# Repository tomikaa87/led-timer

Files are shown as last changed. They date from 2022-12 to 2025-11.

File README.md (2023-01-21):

# led-timer
Programmable timer for low voltage LED lights (e.g. christmas LED strings) with a Microchip PIC16.

**This project is in work-in-progress state**

# Features:
* Sophisticated scheduling system - you can choose from 48 individual 30 minute-length intervals to turn on the LED output
* Controllable LED brightness via PWM (Pulse Width Modulation) in 255 steps
* Dedicated LED driver circuit on the output
* Low power microcontroller - battery-friendly power consumption (LED output current not included)
  * 4 mA (screen on)
  * 0.2 mA (screen off)
  * ~6 μA (deep-sleep, only time-keeping) - more than 2 years from a standard CR2032 lithium battery
* Easy-to-use and intuitive user interface:
  * 3 buttons for changing settings, toggling the output etc.
  * OLED screen with schedule, output state, battery level indication and more
  * Each screen shows a legend for individual key functions
* Backup battery - timekeeping and changing settings work without external power

A custom-made PCB and a 3D-printable enclosure is still in development and should be published soon.

# Case

I've made a simple 3D-printable case in FreeCAD. It's a two-part design which can be assembled using M2 self-tapping screws.

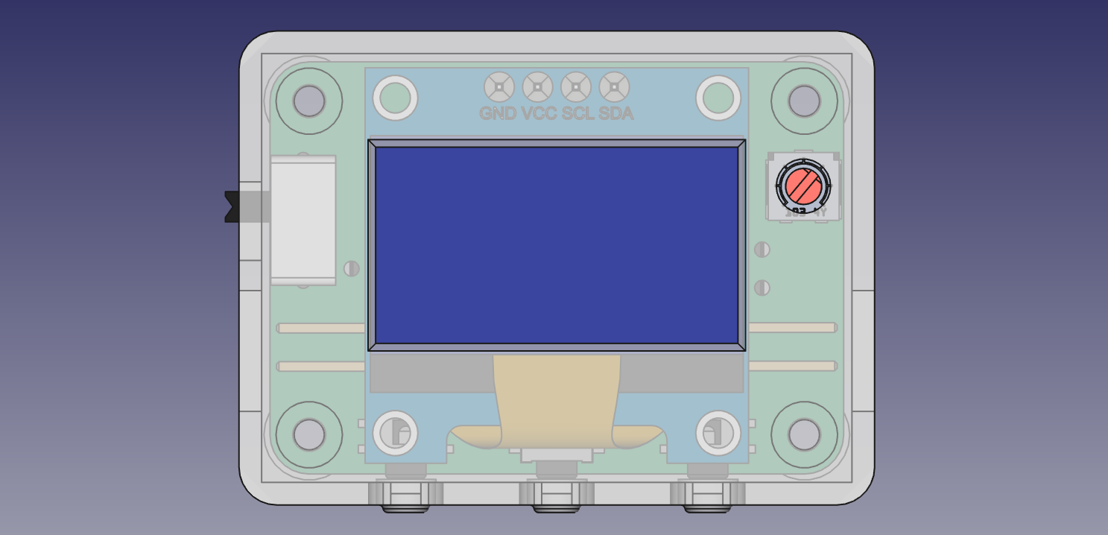
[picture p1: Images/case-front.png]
Front

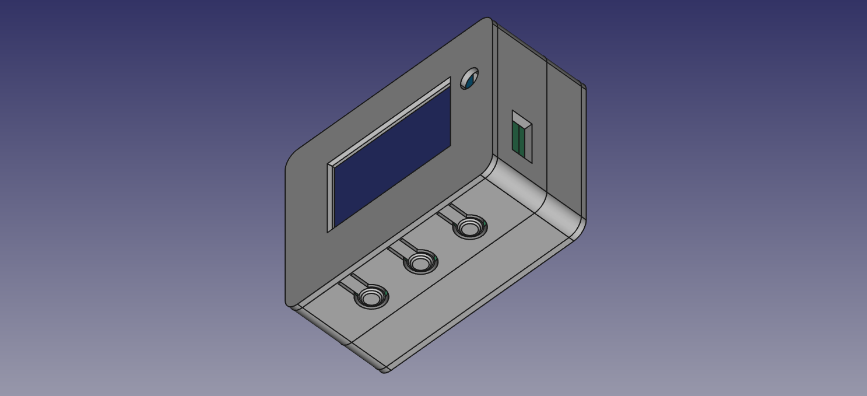
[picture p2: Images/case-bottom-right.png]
Bottom-right

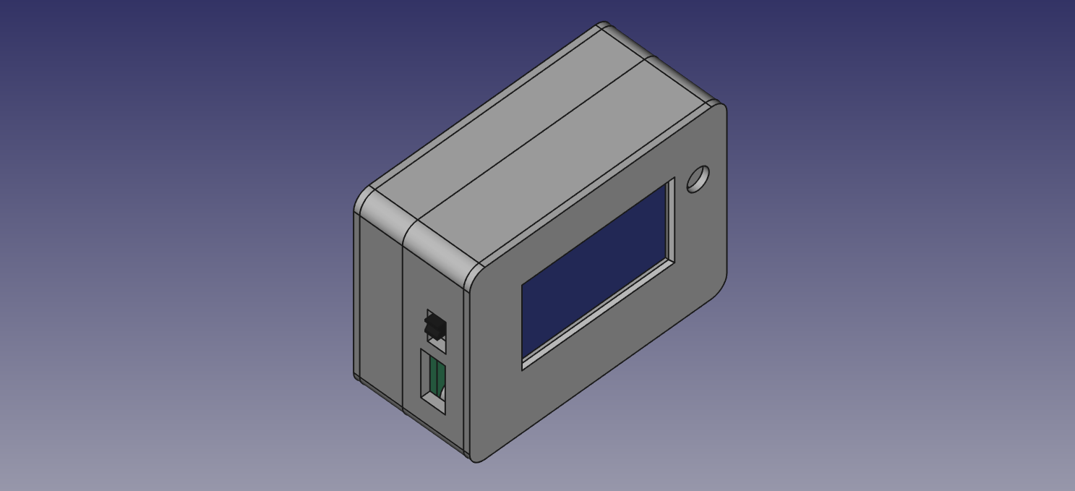
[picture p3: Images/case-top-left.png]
Top-left

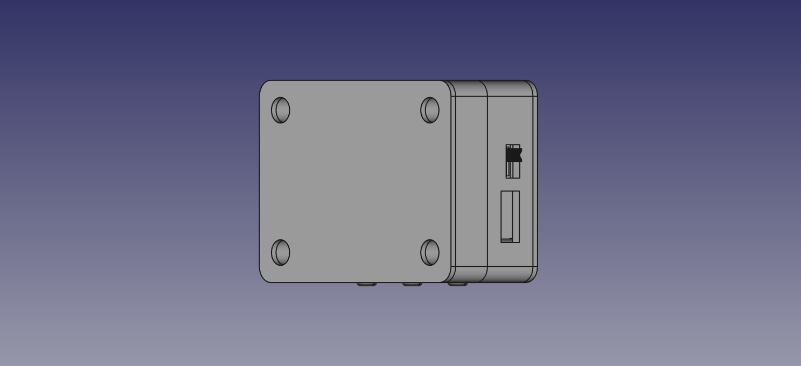
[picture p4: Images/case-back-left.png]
Back-left

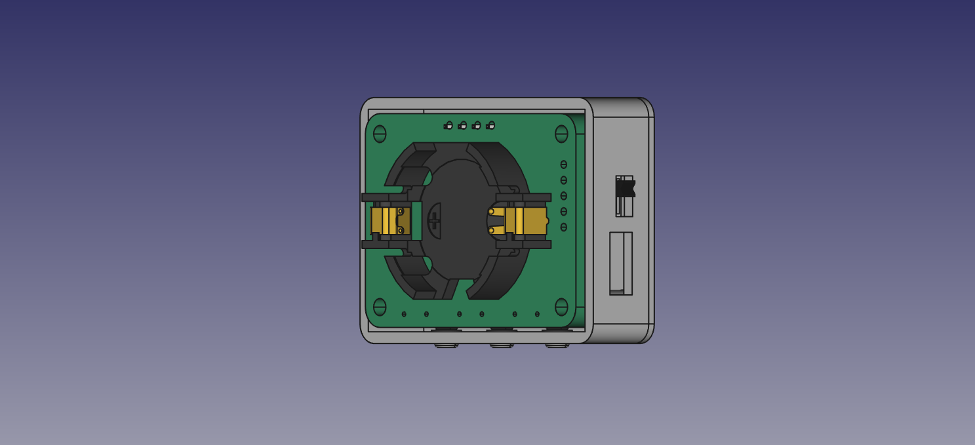
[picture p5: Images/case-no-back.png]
Without back cover


# PCB

The first version of the PCB is a 4-layer design that can be manufactured for $2 at JLC PCB.
It's almost as small as the 0.96" SSD1306 OLED display module itself. Because different display modules have varying pinouts (VDD and GND swapped), the function of the first two pins are configurable via solder jumpers (JP1 and JP2).
The switch on the side can turn of the timer completely to conserve battery power while the timer is in storage.
The three buttons on the bottom are for navigation on the user interface.
The battery holder on the back side receives a standard CR2032 3V lithium cell.
The power input and LED output connectors are standard 2.54 mm pitch pin headers.

The interactive BOM can be accessed HERE

## 3D renders of the PCB

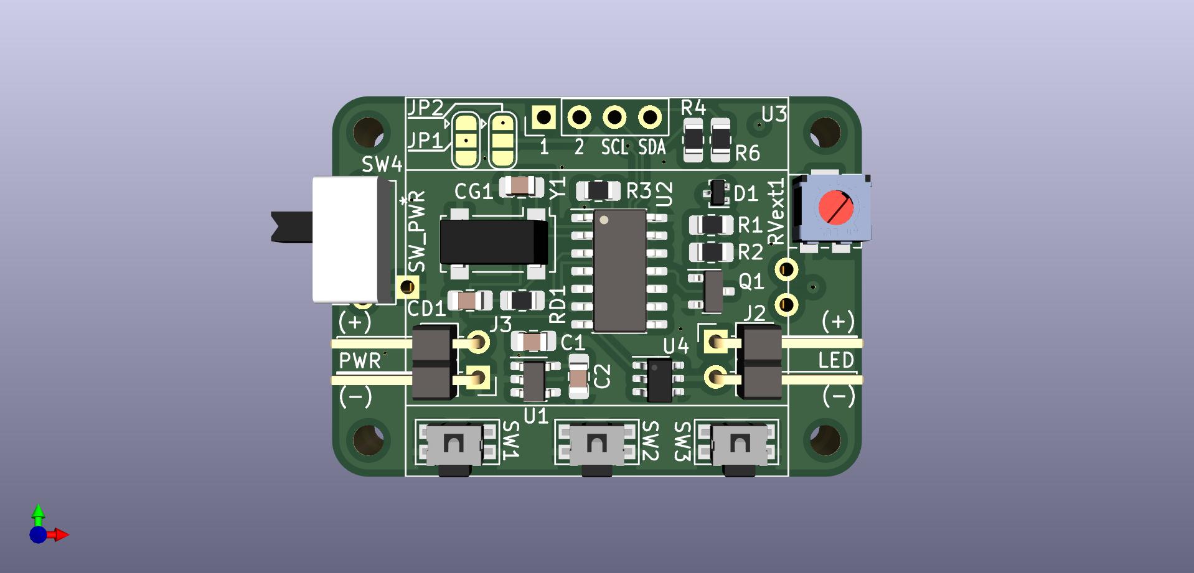
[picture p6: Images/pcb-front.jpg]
Front side


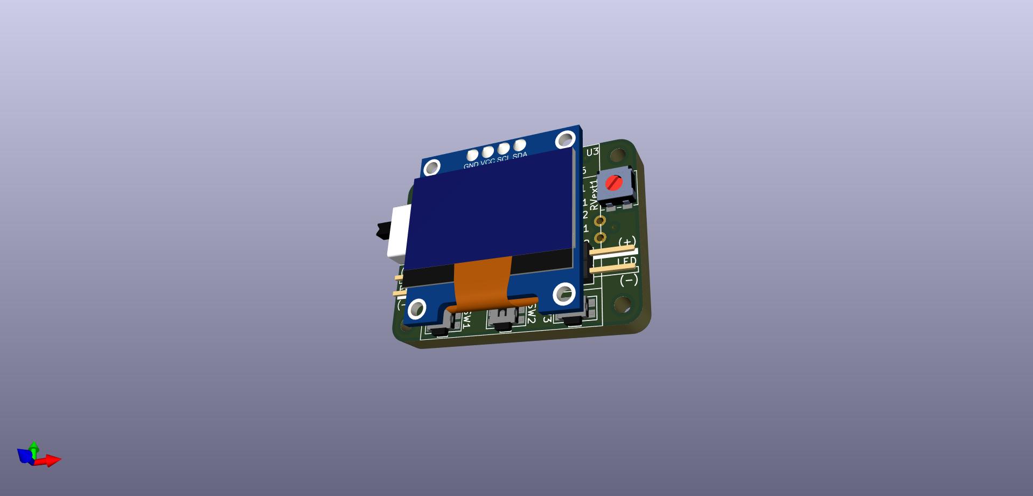
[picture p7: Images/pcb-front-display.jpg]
Front side with display


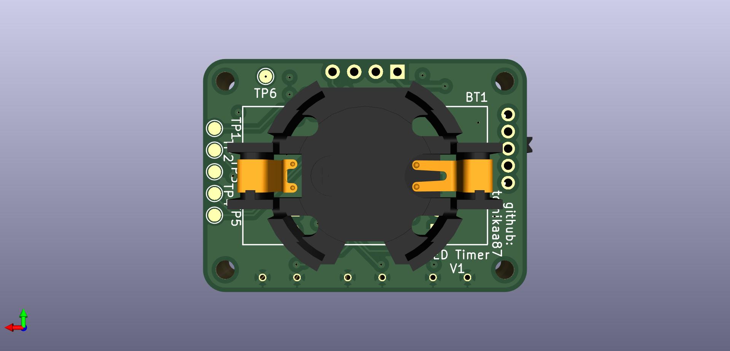
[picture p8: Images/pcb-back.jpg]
Back side


# Images of the prototype

## Main screen
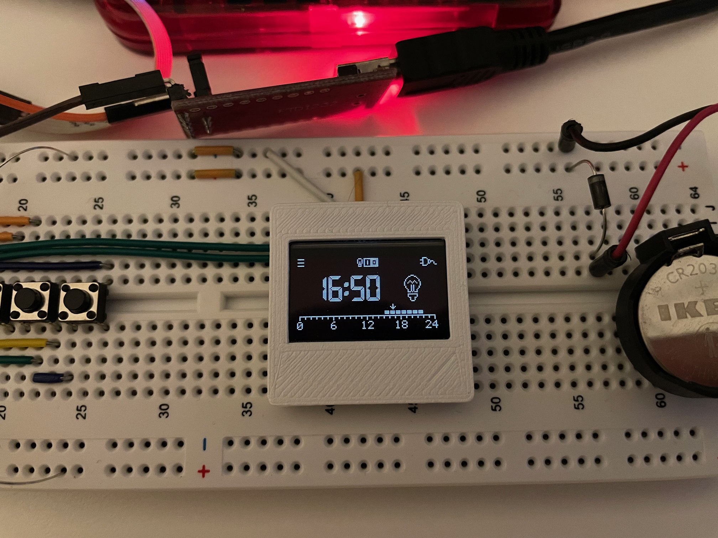
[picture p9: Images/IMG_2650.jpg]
Main screen


## Main screen functions explained
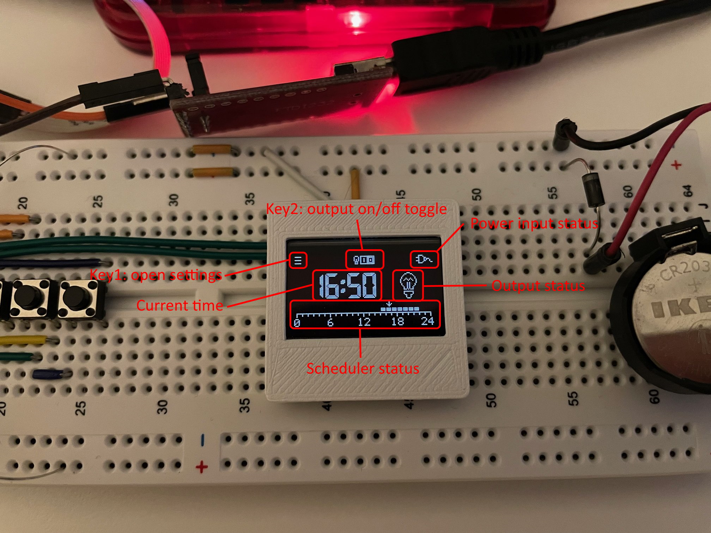
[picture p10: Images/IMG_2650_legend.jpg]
Main screen functions


## Settings screen
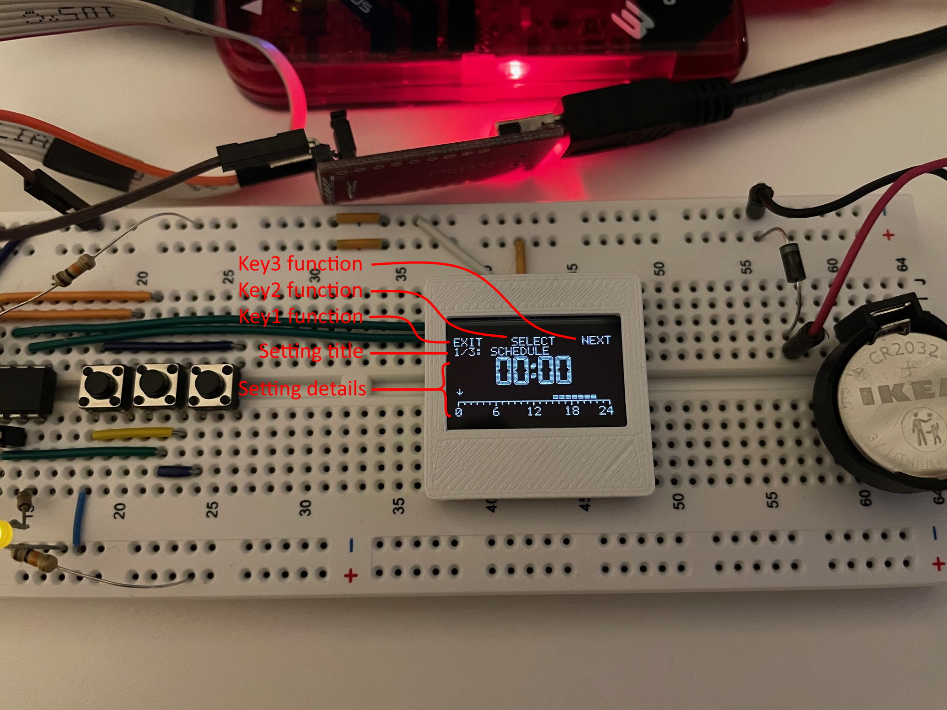
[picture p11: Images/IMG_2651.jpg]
Settings screen


## Scheduler settings
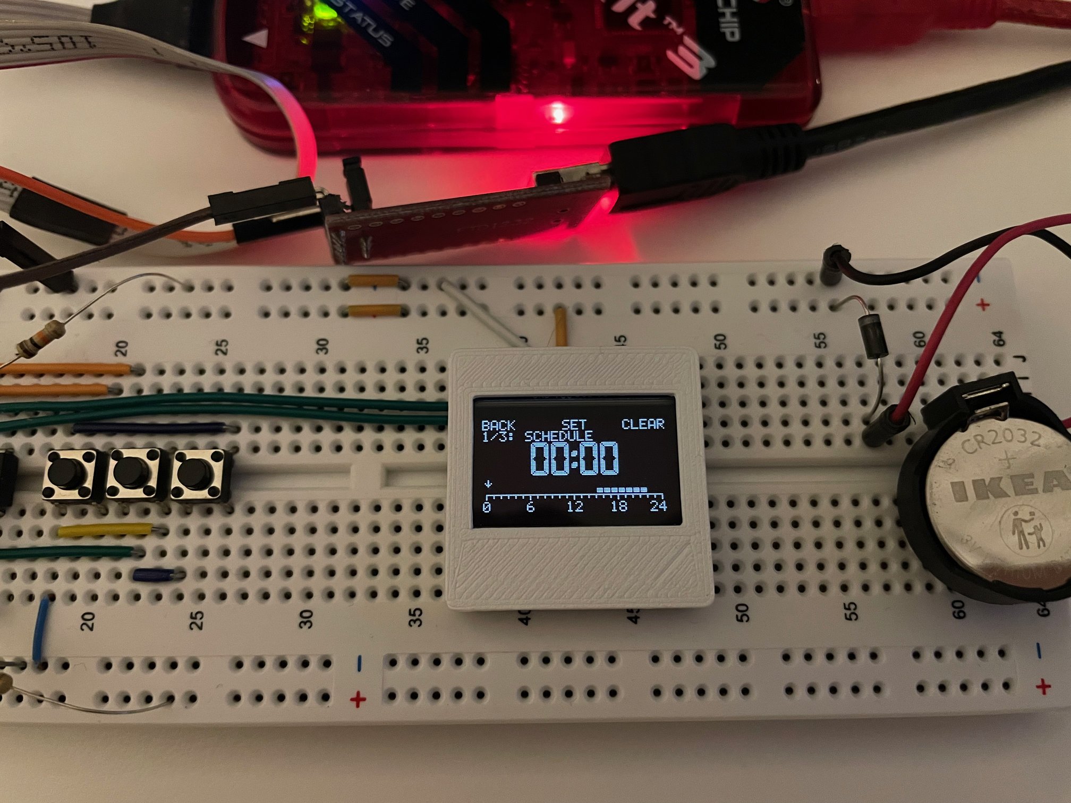
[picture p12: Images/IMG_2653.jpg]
Scheduler settings


## LED output brightness setting
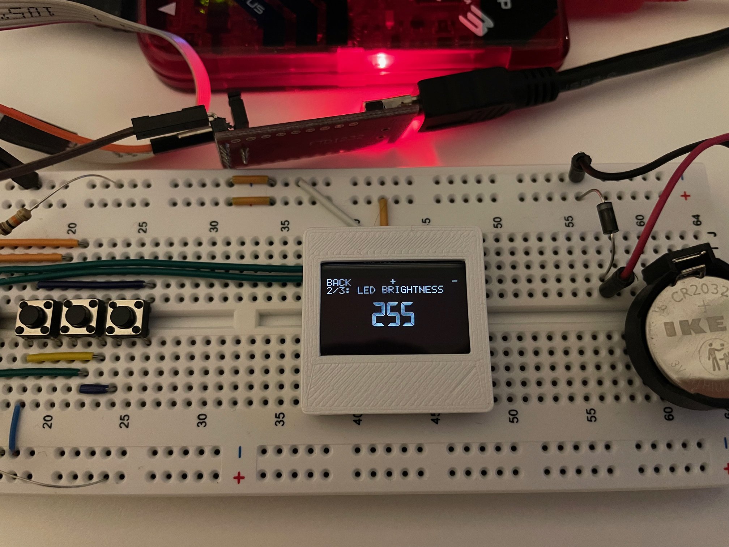
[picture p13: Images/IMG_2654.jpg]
LED brightness setting


## Clock setting
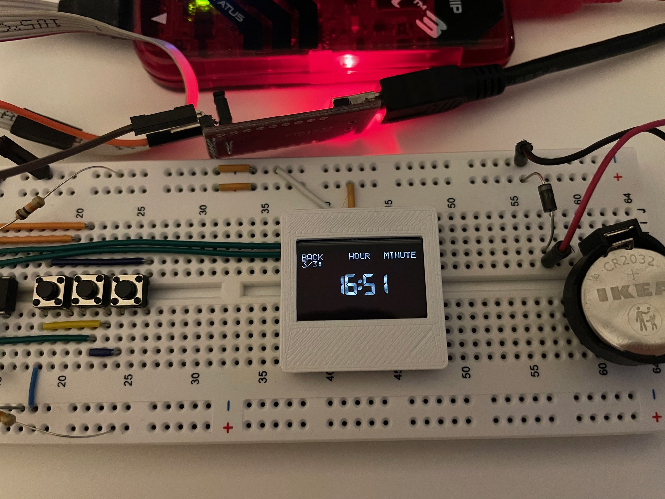
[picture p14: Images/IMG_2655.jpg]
Clock setting


## Prototype setup
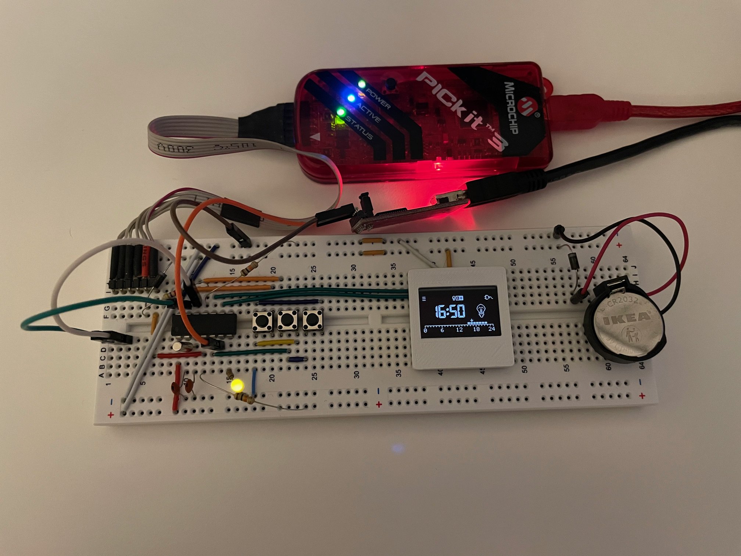
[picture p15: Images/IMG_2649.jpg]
Prototype setup


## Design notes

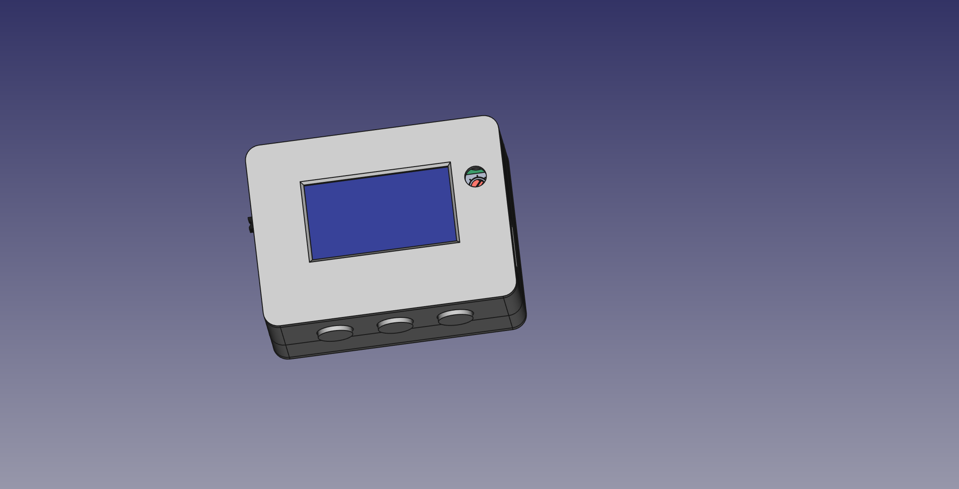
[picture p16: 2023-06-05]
Images/case-v1-front.png

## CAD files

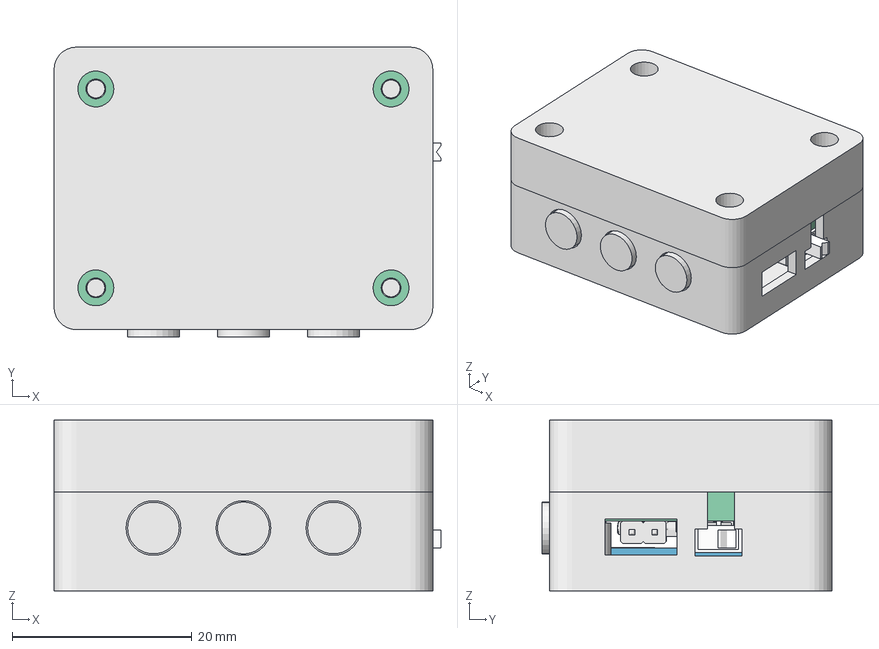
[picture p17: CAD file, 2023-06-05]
Hardware/LEDTimer-Case-v1.FCStd
43.0 x 32.2 x 19.0 mm
Pcb_6a3c
U1_SOT_23_5_c919dfabb42d
R6_R_0805_2012Metric_913303a1058b x 7
ST-4EA
ST-4EA001
ST-4EA002
ST-4EA003
ST-4EA004
ST-4EA005
C2_C_0805_2012Metric_91cd6132d048 x 4
SW3_YD-3414 - Side SMD Switch _6de035d26ca9 x 3
Q1_SOT_23_be697421db99
SW4_1825232-1 v7_d91099a16907
J3_PinHeader_1x02_P254mm_Horizontal_407d359f6e54 x 2
smq32s_корпус
smq32s_контакт
smq32s_контакт001
smq32s_контакт002
smq32s_контакт003
board
board001
board002
board003
board004
board005
board006
board007
board008
screen
screen001
screen002
pin_header
pin_header001
pin_header002
pin_header003
pin_header004
pin_header005
pin_header006
pin_header007
soldering
soldering001
soldering002
soldering003
smd_capacitor
smd_capacitor001
smd_capacitor002
smd_capacitor (1)
smd_capacitor (1)001
smd_capacitor (1)002
914_smd_resistor
914_smd_resistor001
914_smd_resistor002
472_smd_resistor
472_smd_resistor001
472_smd_resistor002
472_smd_resistor004
472_smd_resistor005
472_smd_resistor006
472_smd_resistor008
472_smd_resistor009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

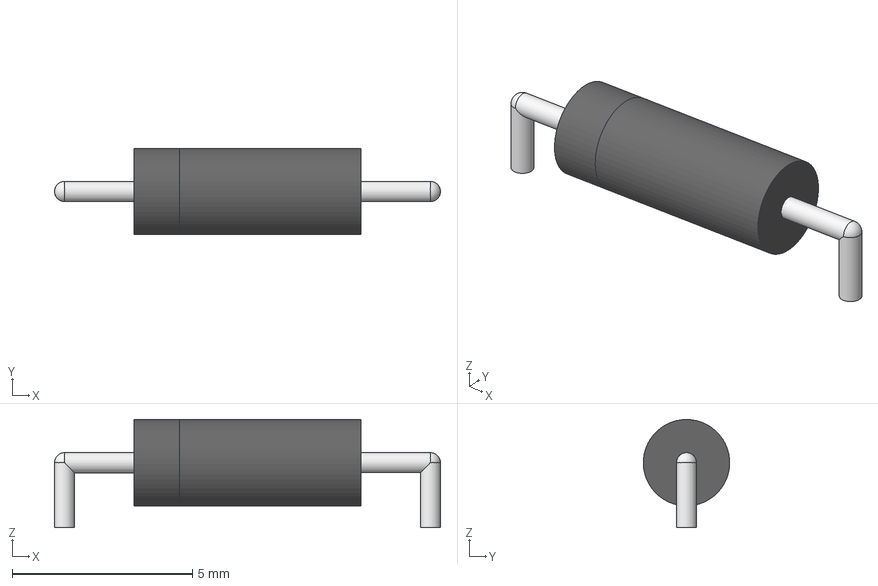
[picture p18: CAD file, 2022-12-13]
Hardware/LEDTimerLite/Batt_Renata_HU2032-LF/eec.models/Renata_-_HU2032-LF.step
10.7 x 2.40 x 3.00 mm

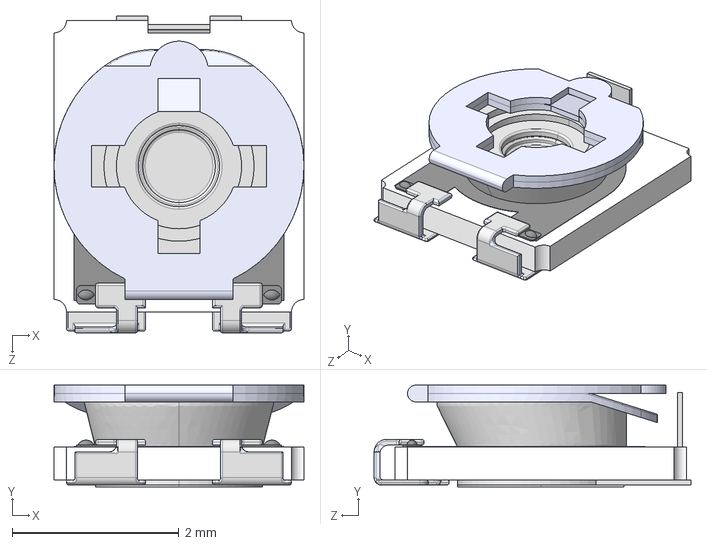
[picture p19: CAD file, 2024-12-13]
Hardware/LEDTimerLite/LIB_TC33X-2-101E/TC33X-2-101E.stp
3.00 x 1.22 x 3.80 mm

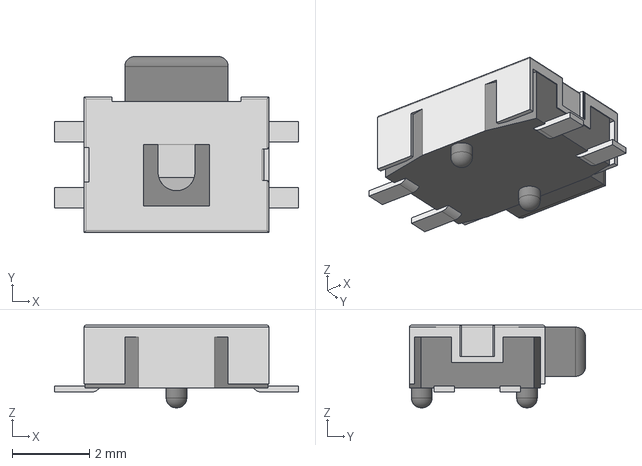
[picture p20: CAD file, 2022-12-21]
Hardware/LEDTimerLite/YD-3414 - Side SMD Switch .stp
6.30 x 4.55 x 2.13 mm

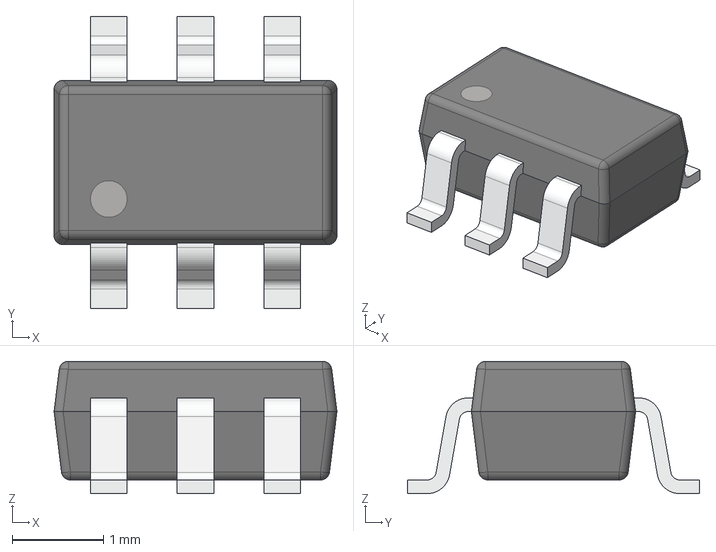
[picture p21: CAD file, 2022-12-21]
Hardware/LEDTimerLite/SC-74-6.stp
3.10 x 3.20 x 1.45 mm

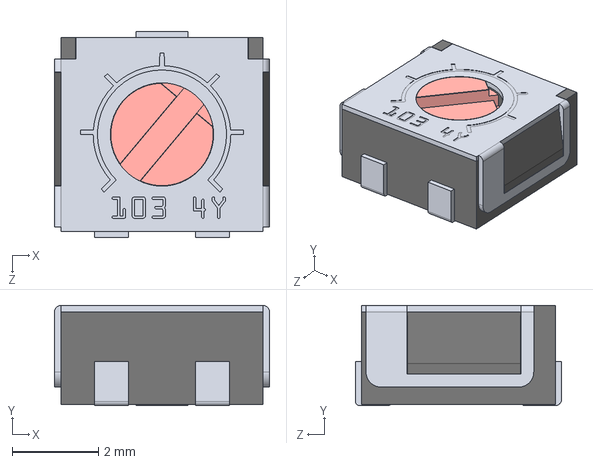
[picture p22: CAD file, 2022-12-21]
Hardware/LEDTimerLite/ST-4EA.STEP
5.00 x 2.33 x 4.80 mm

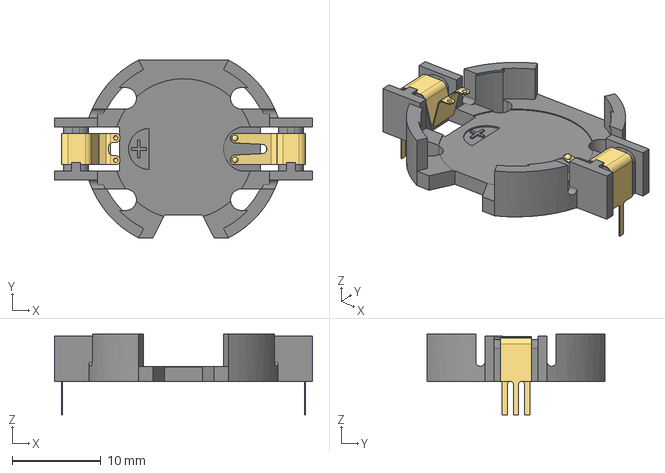
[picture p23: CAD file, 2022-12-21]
Hardware/LEDTimerLite/BU2032-1-HD-G.stp
29.0 x 20.0 x 9.05 mm

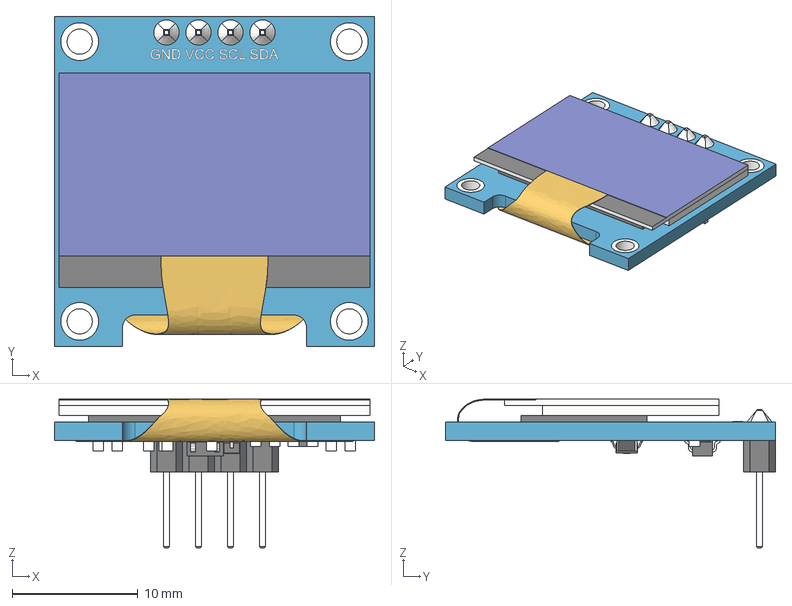
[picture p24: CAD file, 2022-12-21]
Hardware/LEDTimerLite/SSD1306_OLED_Display(128x64).step
25.4 x 26.2 x 11.8 mm
board
screen
pin_header
soldering
smd_capacitor
smd_capacitor (1)
914_smd_resistor
472_smd_resistor x 3
t4_smd_diode
smd_capacitor (2)
smd_capacitor (3)
smd_capacitor (4)
smd_capacitor (5)
smd_capacitor (6)
472_smd_resistor (1)
SOT-23_XC6206 v3
smd_capacitor (7)
flat_cable

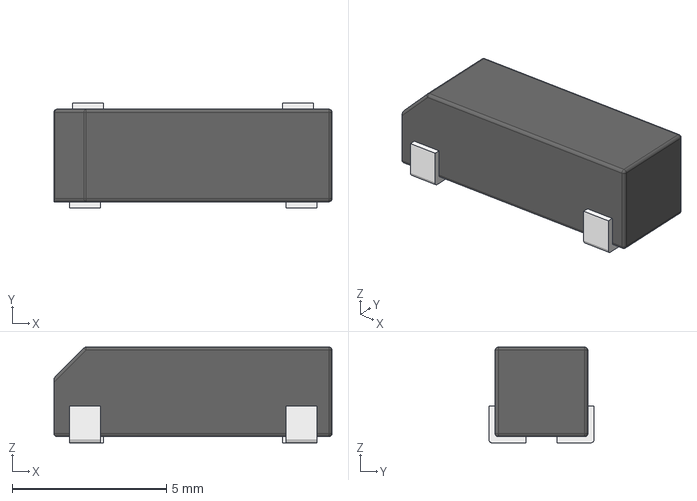
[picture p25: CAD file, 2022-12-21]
Hardware/LEDTimerLite/sqm32s.stp
9.00 x 3.40 x 3.10 mm
smq32s_контакт x 4

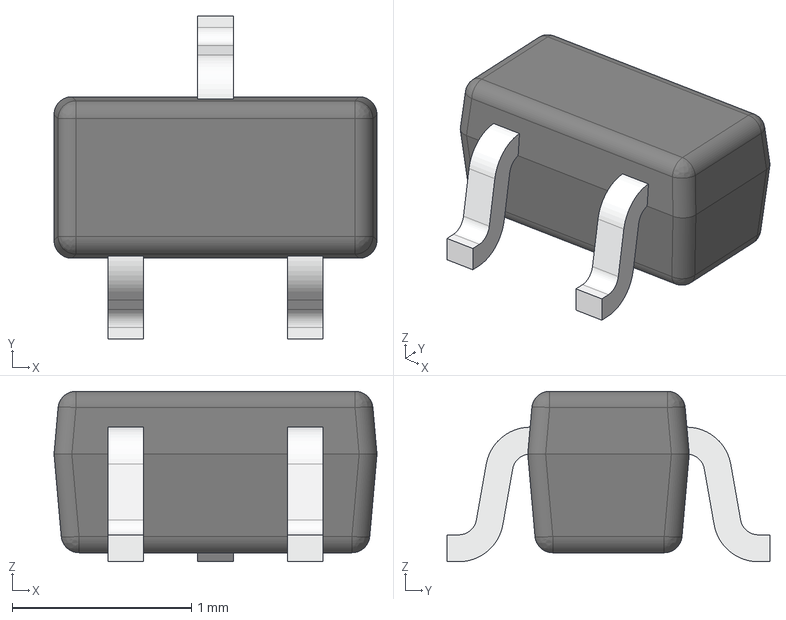
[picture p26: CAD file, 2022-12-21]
Hardware/LEDTimerLite/SC-75.stp
1.80 x 1.80 x 0.95 mm

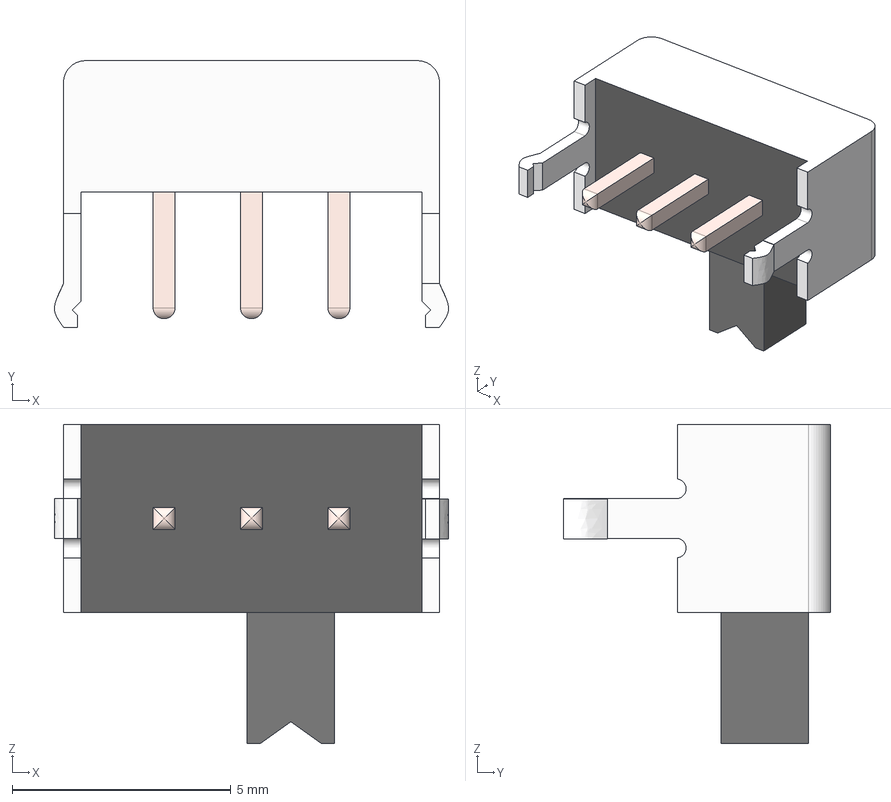
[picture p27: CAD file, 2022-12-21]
Hardware/LEDTimerLite/1825232-1 v7.step
9.01 x 6.10 x 7.30 mm

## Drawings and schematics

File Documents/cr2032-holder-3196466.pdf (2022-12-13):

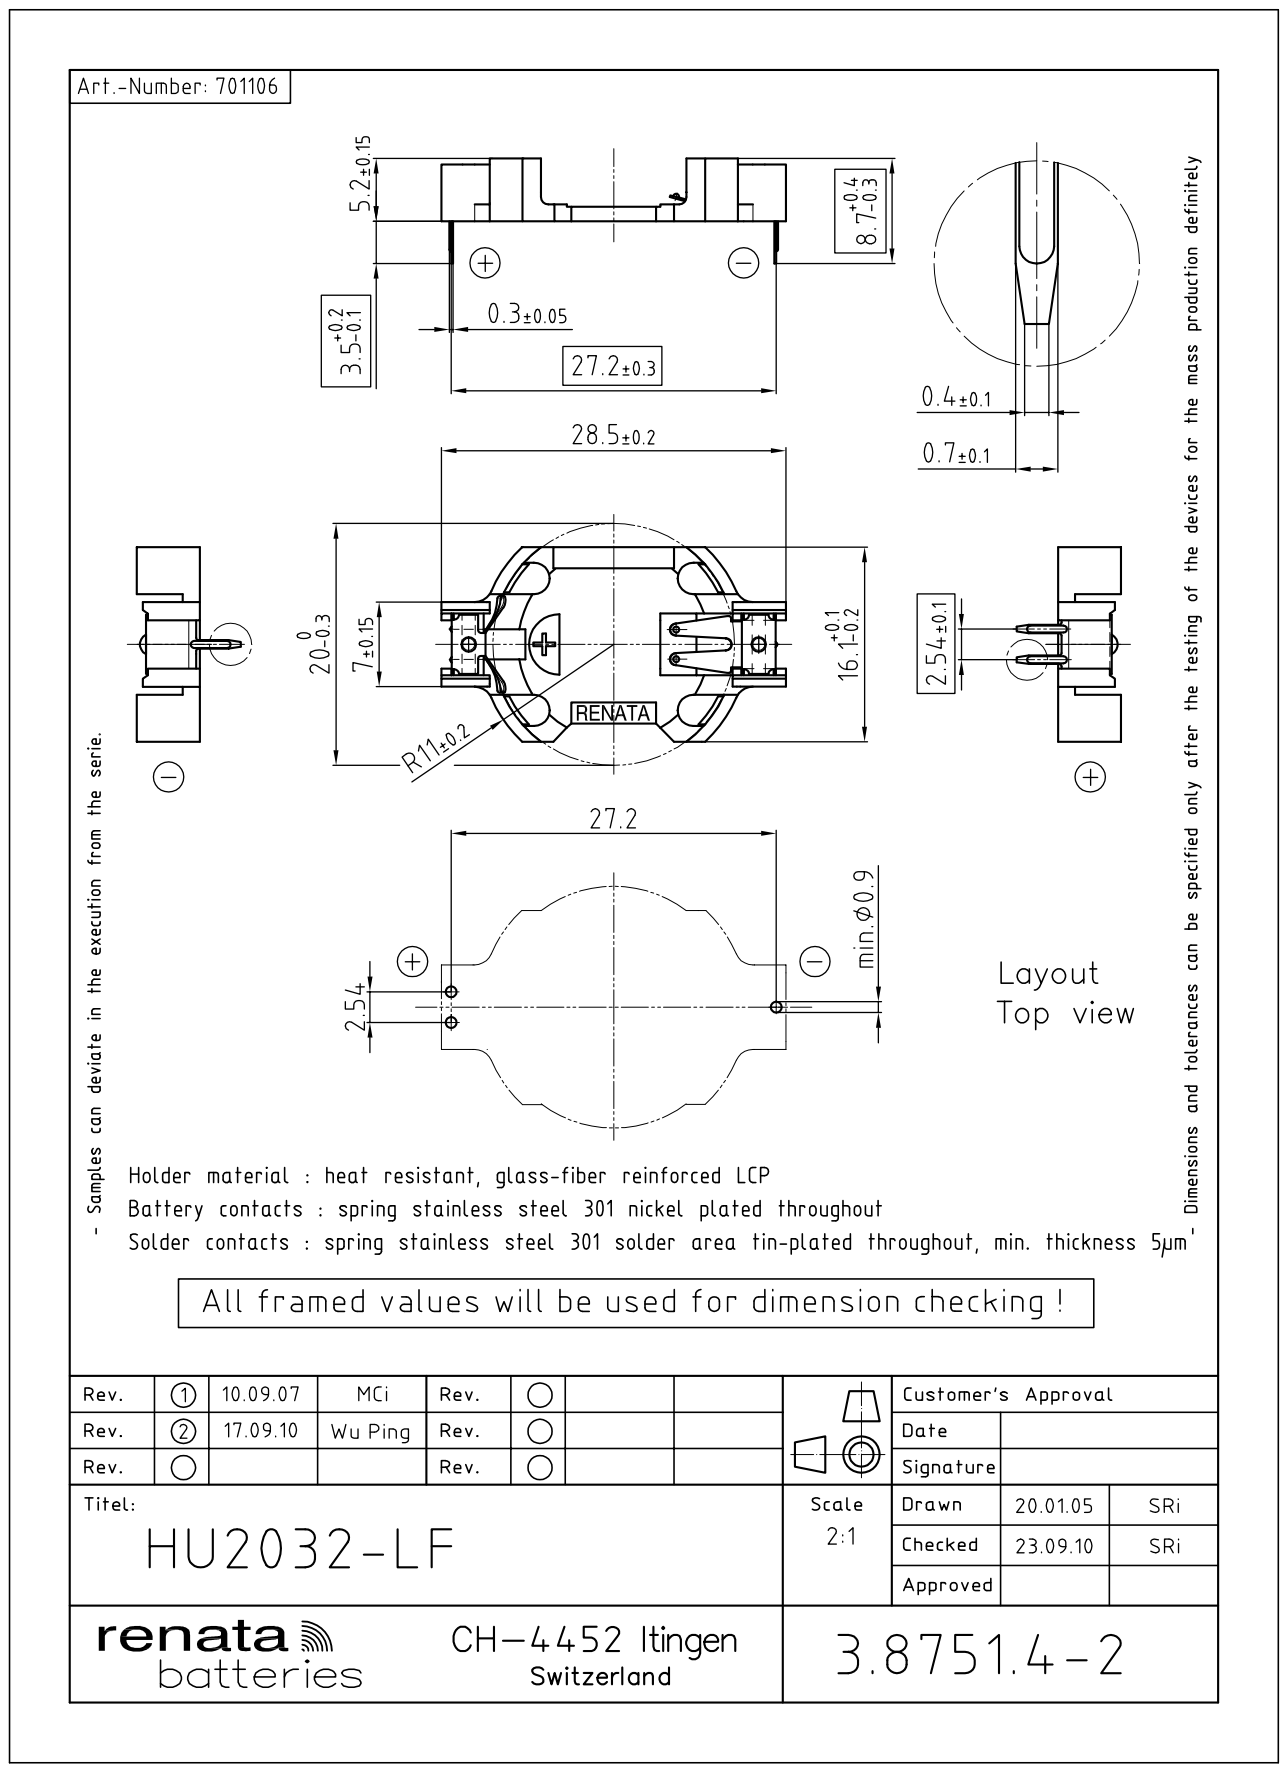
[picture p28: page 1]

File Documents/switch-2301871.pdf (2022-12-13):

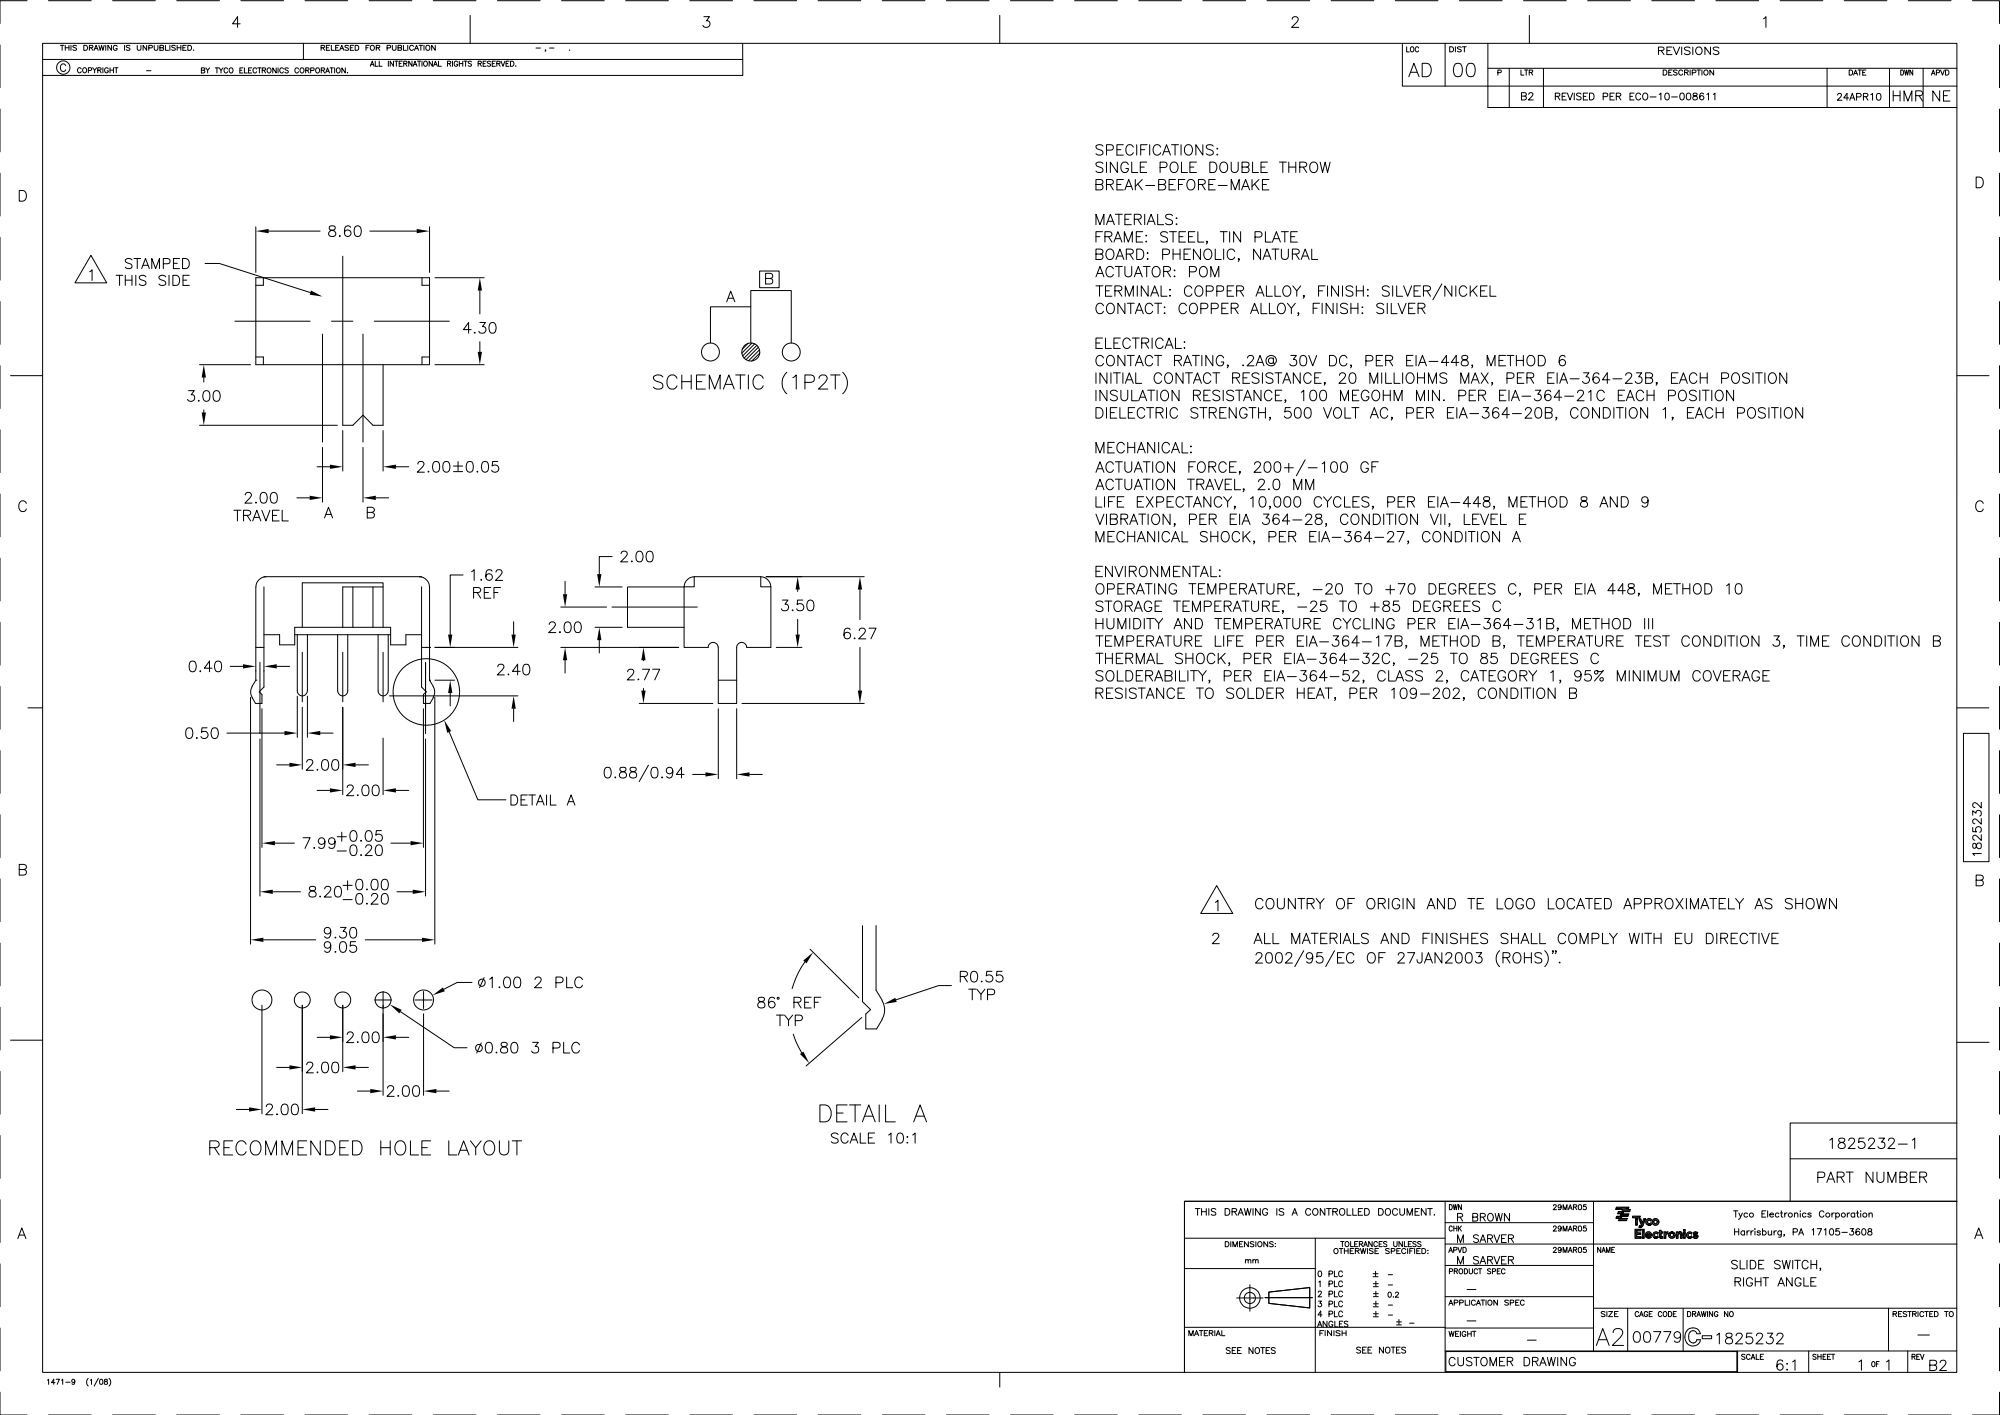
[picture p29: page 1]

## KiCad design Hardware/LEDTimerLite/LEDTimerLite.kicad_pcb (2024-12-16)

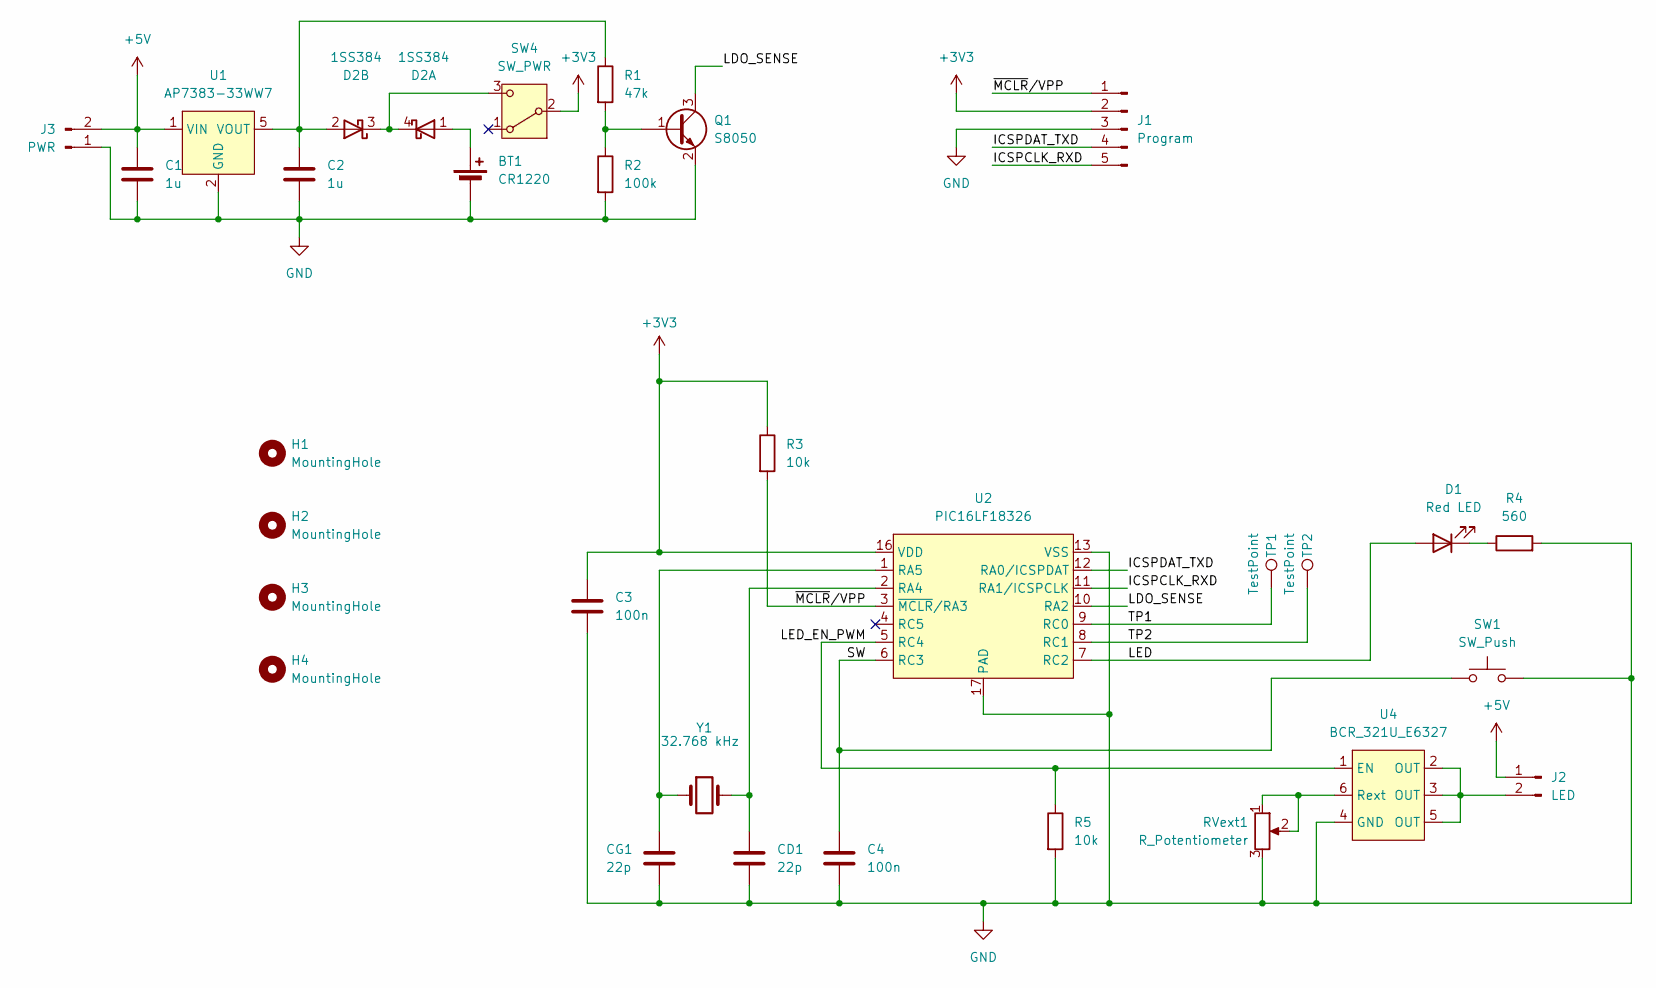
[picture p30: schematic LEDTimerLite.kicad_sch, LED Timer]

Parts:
BT1: CR1220; BatteryHolder_Keystone_3001_1x12mm; mouser part number 614-HU2032-LF; mouser description Coin Cell Battery Holders THRU HOLE FOR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
C1, C2: 1u; C_0805_2012Metric_Pad1.18x1.45mm_HandSolder
C3, C4: 100n; C_0805_2012Metric_Pad1.18x1.45mm_HandSolder
CD1: 22p; C_0805_2012Metric_Pad1.18x1.45mm_HandSolder
CG1: 22p; C_0805_2012Metric_Pad1.18x1.45mm_HandSolder
D1: Red LED; LED_0805_2012Metric_Pad1.15x1.40mm_HandSolder
D2: 1SS384; SOT-343_SC-70-4
H1, H2, H3, H4: MountingHole; MountingHole_2.2mm_M2_Pad_Via
J1: Program; PinHeader_1x05_P2.54mm_Vertical
J2: LED; PinHeader_1x02_P2.54mm_Horizontal
J3: PWR; PinHeader_1x02_P2.54mm_Horizontal
Q1: S8050; SOT-23
R1: 47k; R_0805_2012Metric_Pad1.20x1.40mm_HandSolder
R2: 100k; R_0805_2012Metric_Pad1.20x1.40mm_HandSolder
R3, R5: 10k; R_0805_2012Metric_Pad1.20x1.40mm_HandSolder
R4: 560; R_0805_2012Metric_Pad1.20x1.40mm_HandSolder
RVext1: R_Potentiometer; Potentiometer_Bourns_TC33X_Vertical
SW1: SW_Push; SW_SPST_TL3305A
SW4: SW_PWR; 1825232-1
TP1, TP2: TestPoint; TestPoint_Pad_D1.5mm
U1: AP7383-33WW7; SOT-23-5
U2: PIC16LF18326; UQFN-16-1EP_4x4mm_P0.65mm_EP2.6x2.6mm
U4: BCR_321U_E6327; SC-74-6_1.55x2.9mm_P0.95mm
Y1: 32.768 kHz; Crystal_SMD_MicroCrystal_CC8V-T1A-2Pin_2.0x1.2mm_HandSolder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

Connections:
+3V3: C3.1, J1.2, R3.1, SW4.2 (B), U2.16 (VDD)
+5V: C1.1, J2.1, J3.2, U1.1 (VIN)
/ICSPCLK_RXD: J1.5, U2.11 (RA1/ICSPCLK)
/ICSPDAT_TXD: J1.4, U2.12 (RA0/ICSPDAT)
/LDO_SENSE: Q1.3 (C), U2.10 (RA2)
/LED: D1.2 (A), U2.7 (RC2)
/LED_EN_PWM: R5.1, U2.5 (RC4), U4.1 (EN)
/SW: C4.1, SW1.2, U2.6 (RC3)
/TP1: TP1.1, U2.9 (RC0)
/TP2: TP2.1, U2.8 (RC1)
/~MCLR/VPP: J1.1, R3.2, U2.3 (~MCLR/RA3)
GND: BT1.2 (-), C1.2, C2.2, C3.2, C4.2, CD1.2, CG1.2, J1.3, J3.1, Q1.2 (E), R2.2, R4.2, R5.2, RVext1.3, SW1.1, U1.2 (GND), U2.13 (VSS), U2.17 (PAD), U4.4 (GND)
unnamed: BT1.1 (+), D2.1 (A)
unnamed: D1.1 (K), R4.1
unnamed: D2.3 (K), D2.4 (K), SW4.3 (C)
unnamed: C2.1, D2.2 (A), R1.1, U1.5 (VOUT)
unnamed: J2.2, U4.2 (OUT), U4.3 (OUT), U4.5 (OUT)
unnamed: Q1.1 (B), R1.2, R2.1
unnamed: CD1.1, U2.2 (RA4), Y1.2
unnamed: CG1.1, U2.1 (RA5), Y1.1
unnamed: RVext1.1, RVext1.2, U4.6 (Rext)

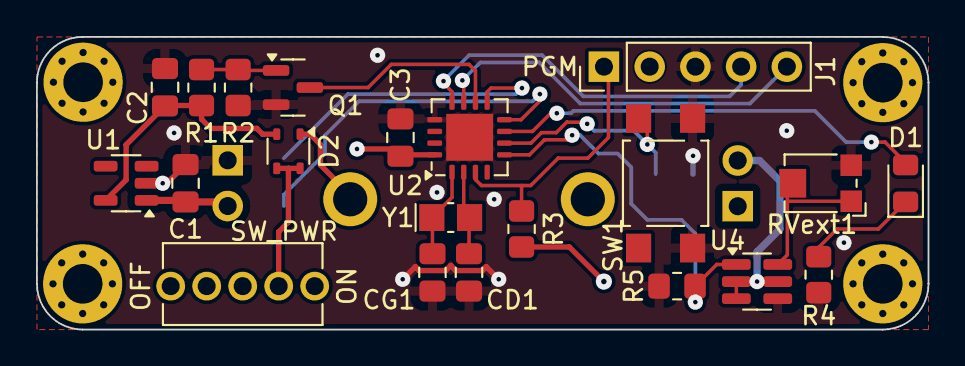
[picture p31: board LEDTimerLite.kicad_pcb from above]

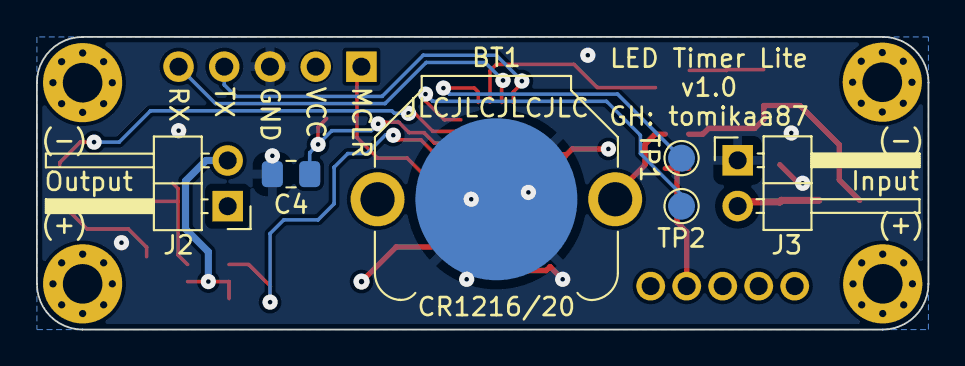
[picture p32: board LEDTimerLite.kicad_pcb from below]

Board: 4 copper layers, 49.5 x 16.3 mm, 31 parts (6 on the bottom side), 21 nets.

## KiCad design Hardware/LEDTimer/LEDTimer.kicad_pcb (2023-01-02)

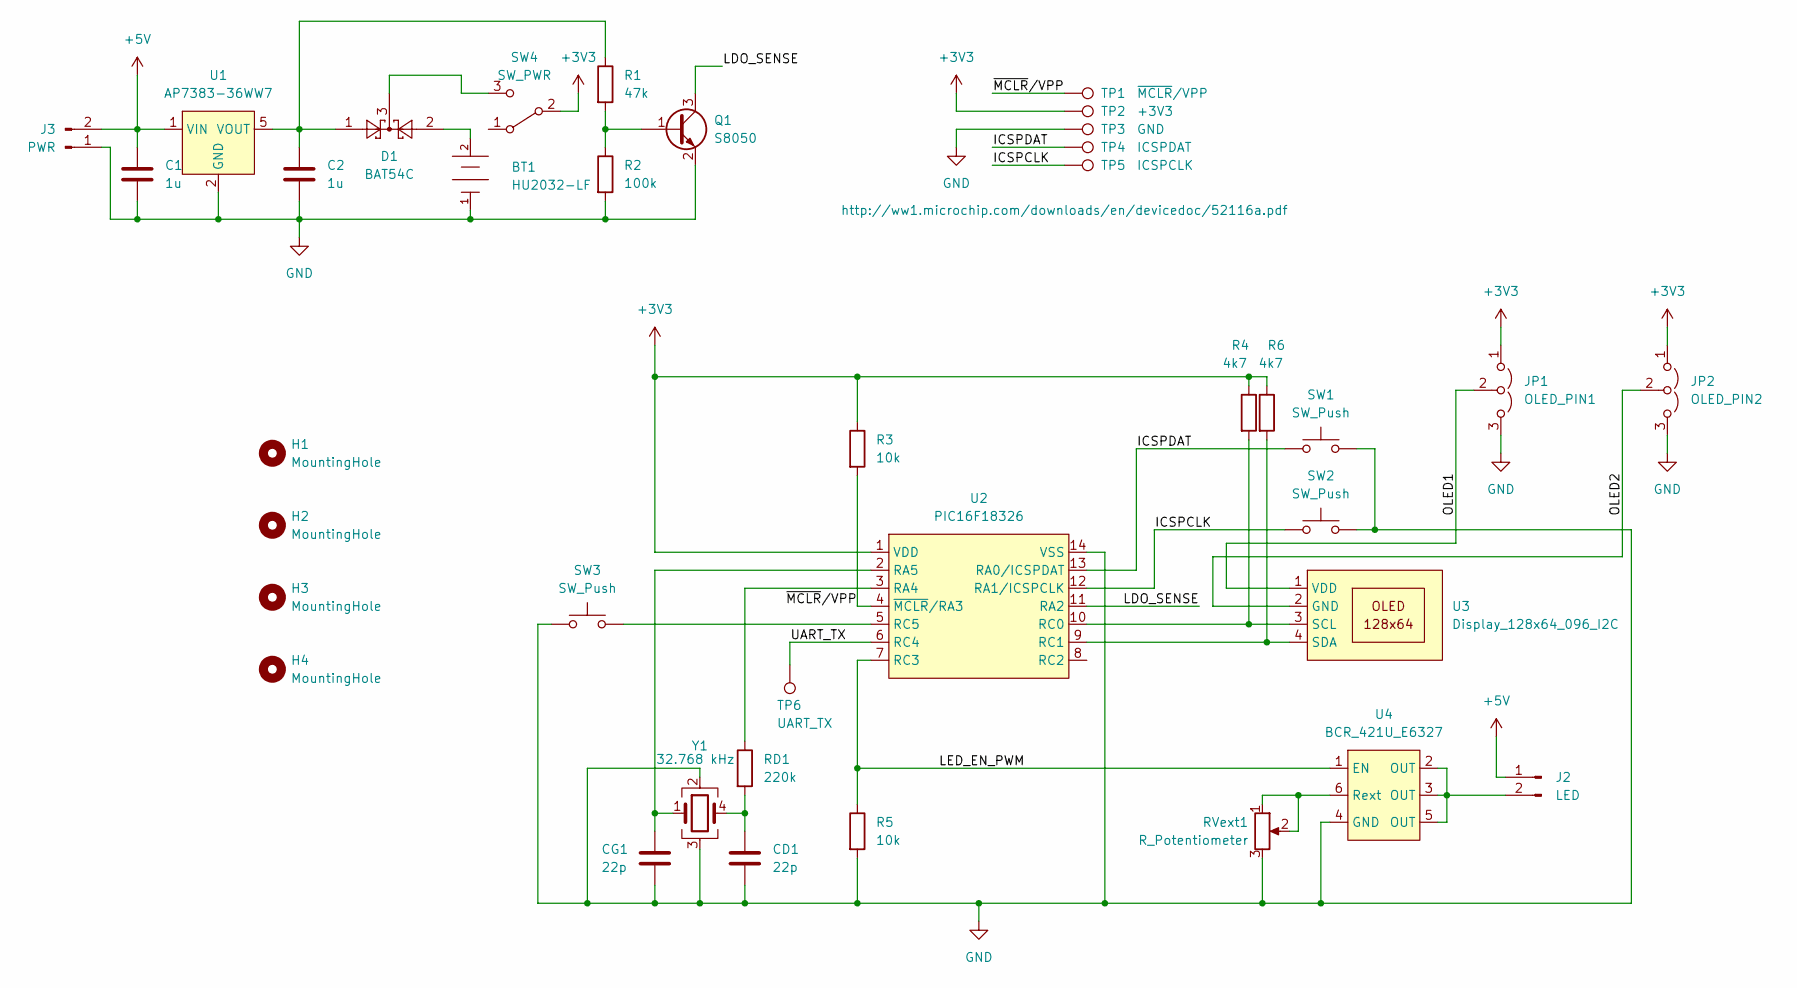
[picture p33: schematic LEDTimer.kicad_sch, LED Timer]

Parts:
BT1: HU2032-LF; Renata-HU2032-LF-0-0-0; mouser part number 614-HU2032-LF; mouser description Coin Cell Battery Holders THRU HOLE FOR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
C1, C2: 1u; C_0805_2012Metric_Pad1.18x1.45mm_HandSolder
CD1: 22p; C_0805_2012Metric_Pad1.18x1.45mm_HandSolder
CG1: 22p; C_0805_2012Metric_Pad1.18x1.45mm_HandSolder
D1: BAT54C; SOT-416
H1, H2, H3, H4: MountingHole; MountingHole_2.2mm_M2
J2: LED; PinHeader_1x02_P2.54mm_Horizontal
J3: PWR; PinHeader_1x02_P2.54mm_Horizontal
JP1: OLED_PIN1; SolderJumper-3_P1.3mm_Open_RoundedPad1.0x1.5mm
JP2: OLED_PIN2; SolderJumper-3_P1.3mm_Open_RoundedPad1.0x1.5mm
Q1: S8050; SOT-23
R1: 47k; R_0805_2012Metric_Pad1.20x1.40mm_HandSolder
R2: 100k; R_0805_2012Metric_Pad1.20x1.40mm_HandSolder
R3, R5: 10k; R_0805_2012Metric_Pad1.20x1.40mm_HandSolder
R4, R6: 4k7; R_0805_2012Metric_Pad1.20x1.40mm_HandSolder
RD1: 220k; R_0805_2012Metric_Pad1.20x1.40mm_HandSolder
RVext1: R_Potentiometer; Potentiometer_Vishay_TS53YJ_Vertical
SW1, SW2, SW3: SW_Push; EVQ9P701P
SW4: SW_PWR; 1825232-1
TP1: ~{MCLR}/VPP; TestPoint_Pad_D1.5mm
TP2: +3V3; TestPoint_Pad_D1.5mm
TP3: GND; TestPoint_Pad_D1.5mm
TP4: ICSPDAT; TestPoint_Pad_D1.5mm
TP5: ICSPCLK; TestPoint_Pad_D1.5mm
TP6: UART_TX; TestPoint_Pad_D1.5mm
U1: AP7383-36WW7; SOT-23-5
U2: PIC16F18326; SOIC-14_3.9x8.7mm_P1.27mm
U3: Display_128x64_096_I2C
U4: BCR_421U_E6327; SC-74-6_1.5x2.9mm_P0.95mm
Y1: 32.768 kHz; Crystal_SMD_Abracon_ABS25-4Pin_8.0x3.8mm

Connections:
+3V3: JP1.1 (A), JP2.1 (A), R3.1, R4.1, R6.1, SW4.2 (B), TP2.1, U2.1 (VDD)
+5V: C1.1, J2.1, J3.2, U1.1 (VIN)
/ICSPCLK: SW2.2, TP5.1, U2.12 (RA1/ICSPCLK)
/ICSPDAT: SW1.2, TP4.1, U2.13 (RA0/ICSPDAT)
/LDO_SENSE: Q1.3 (C), U2.11 (RA2)
/LED_EN_PWM: R5.1, U2.7 (RC3), U4.1 (EN)
/OLED1: JP1.2 (C), U3.1 (VDD)
/OLED2: JP2.2 (C), U3.2 (GND)
/UART_TX: TP6.1, U2.6 (RC4)
/~MCLR/VPP: R3.2, TP1.1, U2.4 (~MCLR/RA3)
GND: BT1.1 (CATHODE), C1.2, C2.2, CD1.2, CG1.2, J3.1, JP1.3 (B), JP2.3 (B), Q1.2 (E), R2.2, R5.2, RVext1.3, SW1.1, SW2.1, SW3.1, TP3.1, U1.2 (GND), U2.14 (VSS), U4.4 (GND), Y1.2, Y1.3
unnamed: BT1.2 (ANODE), D1.2
unnamed: C2.1, D1.1, R1.1, U1.5 (VOUT)
unnamed: CD1.1, RD1.2, Y1.4
unnamed: CG1.1, U2.2 (RA5), Y1.1
unnamed: D1.3, SW4.3 (C)
unnamed: J2.2, U4.2 (OUT), U4.3 (OUT), U4.5 (OUT)
unnamed: Q1.1 (B), R1.2, R2.1
unnamed: R4.2, U2.10 (RC0), U3.3 (SCL)
unnamed: R6.2, U2.9 (RC1), U3.4 (SDA)
unnamed: RD1.1, U2.3 (RA4)
unnamed: RVext1.1, RVext1.2, U4.6 (Rext)
unnamed: SW3.2, U2.5 (RC5)

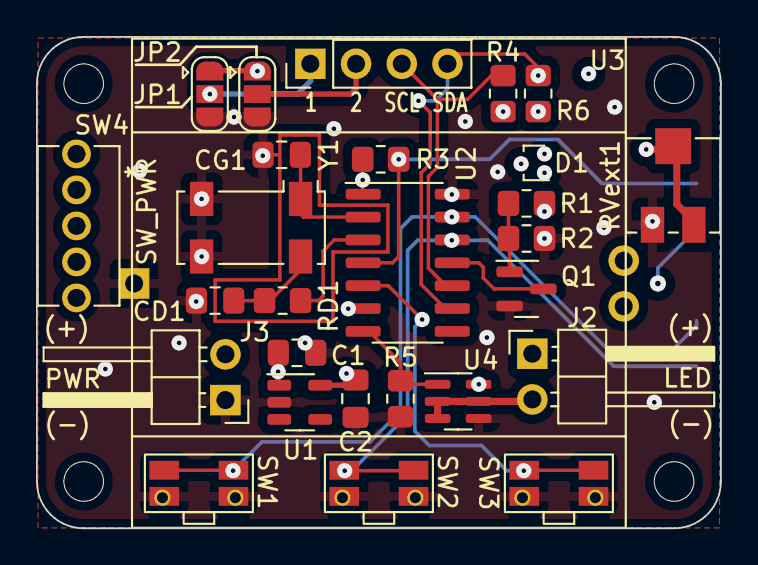
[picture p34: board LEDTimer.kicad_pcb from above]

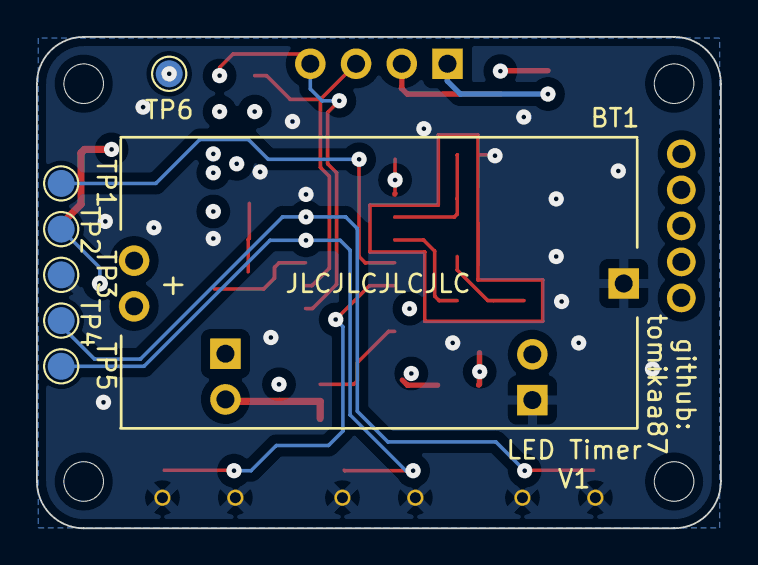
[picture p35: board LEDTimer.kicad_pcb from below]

Board: 4 copper layers, 38.0 x 27.3 mm, 38 parts (7 on the bottom side), 23 nets.

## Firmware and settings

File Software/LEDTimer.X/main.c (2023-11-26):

/**
  Generated Main Source File

  Company:
    Microchip Technology Inc.

  File Name:
    main.c

  Summary:
    This is the main file generated using PIC10 / PIC12 / PIC16 / PIC18 MCUs

  Description:
    This header file provides implementations for driver APIs for all modules selected in the GUI.
    Generation Information :
        Product Revision  :  PIC10 / PIC12 / PIC16 / PIC18 MCUs - 1.81.8
        Device            :  PIC16F18326
        Driver Version    :  2.00
*/

/*
    (c) 2018 Microchip Technology Inc. and its subsidiaries.

    Subject to your compliance with these terms, you may use Microchip software and any
    derivatives exclusively with Microchip products. It is your responsibility to comply with third party
    license terms applicable to your use of third party software (including open source software) that
    may accompany Microchip software.

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
    IN NO EVENT WILL MICROCHIP BE LIABLE FOR ANY INDIRECT, SPECIAL, PUNITIVE,
    INCIDENTAL OR CONSEQUENTIAL LOSS, DAMAGE, COST OR EXPENSE OF ANY KIND
    WHATSOEVER RELATED TO THE SOFTWARE, HOWEVER CAUSED, EVEN IF MICROCHIP
    HAS BEEN ADVISED OF THE POSSIBILITY OR THE DAMAGES ARE FORESEEABLE. TO
    THE FULLEST EXTENT ALLOWED BY LAW, MICROCHIP'S TOTAL LIABILITY ON ALL
    CLAIMS IN ANY WAY RELATED TO THIS SOFTWARE WILL NOT EXCEED THE AMOUNT
    OF FEES, IF ANY, THAT YOU HAVE PAID DIRECTLY TO MICROCHIP FOR THIS
    SOFTWARE.
*/

#include "mcc_generated_files/mcc.h"

#include "Clock.h"
#include "Config.h"
#include "Graphics.h"
#include "Keypad.h"
#include "OutputController.h"
#include "Settings.h"
#include "SSD1306.h"
#include "System.h"
#include "Text.h"
#include "UI.h"

// FIXME for testing
#include "SunsetSunrise.h"

#include <stdio.h>
#include <stdbool.h>

static struct MainContext
{
    volatile bool adcConversionFinished;
} context = {
    .adcConversionFinished = false
};

void __interrupt() isr(void)
{
    if (IOCIE && IOCIF) {
        // RA0 IOC - SW1
        if (IOCAF0) {
            IOCAF0 = 0;
            System_handleExternalWakeUp();
        }

        // RA1 IOC - SW2
        if (IOCAF1) {
            IOCAF1 = 0;
            System_handleExternalWakeUp();
        }

        // RC5 IOC - SW3
        if (IOCCF5) {
            IOCCF5 = 0;
            System_handleExternalWakeUp();
        }

        // RA2 IOC - LDO_SENSE
        if (IOCAF2) {
            IOCAF2 = 0;
            System_handleLDOSenseInterrupt();
        }
    }

    if (PEIE) {
        if (ADIE && ADIF) {
            ADIF = 0;
            System_handleADCInterrupt(((uint16_t)ADRESH) << 8 | ADRESL);
            context.adcConversionFinished = true;
        }

        if (TMR4IE & TMR4IF) {
            TMR4IF = 0;
            Clock_handleFastTimerInterrupt();
        }

        if (TMR1IE & TMR1IF) {
            TMR1IF = 0;
            Clock_handleRTCTimerInterrupt();
        }
    }
}

inline static void setupI2C()
{
    SSP1CON1bits.SSPEN = 1;
}

inline static void showStartupScreen()
{
    SSD1306_clear();

    static const char Title[] = "LED TIMER";
    static const char GitHub[] = "GITHUB.COM/TOMIKAA87";

    uint8_t iconPos = 64 - (CalculateTextWidth(Title) + 5 + 5) / 2;

    Graphics_drawBitmap(Graphics_MiniBulbIcon, 5, iconPos, 1, 0);
    Text_draw(Title, 1, iconPos + 10, 0, false);

    static const char FirmwareVersion[] = "V" Config_FirmwareVersion;

    Text_draw(
        FirmwareVersion,
        3,
        64 - CalculateTextWidth(FirmwareVersion) / 2,
        0,
        false
    );

    Text_draw(GitHub, 6, 64 - CalculateTextWidth(GitHub) / 2, 0, false);

    if (PCON0bits.STKOVF) {
        Text_draw("O", 0, 0, 0, false);
        PCON0bits.STKOVF = 0;
    }

    if (PCON0bits.STKUNF) {
        Text_draw("U", 0, 6, 0, false);
        PCON0bits.STKUNF = 0;
    }

    if (!PCON0bits.nRWDT) {
        Text_draw("U", 0, 12, 0, false);
        PCON0bits.nRWDT = 1;
    }

    if (!PCON0bits.nRMCLR) {
        Text_draw("M", 0, 18, 0, false);
        PCON0bits.nRMCLR = 1;
    }

    if (!PCON0bits.nRI) {
        Text_draw("I", 0, 24, 0, false);
        PCON0bits.nRI = 1;
    }

    if (BORRDY && !PCON0bits.nBOR) {
        Text_draw("B", 0, 30, 0, false);
        PCON0bits.nBOR = 1;
    }
}

/*
                         Main application
 */
void main(void)
{
    // initialize the device
    SYSTEM_Initialize();

    // When using interrupts, you need to set the Global and Peripheral Interrupt Enable bits
    // Use the following macros to:

    // Enable the Global Interrupts
    INTERRUPT_GlobalInterruptEnable();

    // Enable the Peripheral Interrupts
    INTERRUPT_PeripheralInterruptEnable();

    // Disable the Global Interrupts
    //INTERRUPT_GlobalInterruptDisable();

    // Disable the Peripheral Interrupts
    //INTERRUPT_PeripheralInterruptDisable();

    // Enable low-power sleep mode
    VREGPM = 1;

    setupI2C();

    __delay_ms(100);
    SSD1306_init();

    System_init();
    Keypad_init();
    Settings_init();
    Settings_load();

    SSD1306_setContrastLevel(
        System_isRunningFromBackupBattery()
            ? SSD1306_CONTRAST_LOWEST
            : Settings_data.display.brightness
    );

    showStartupScreen();

    // Sunrise/Sunset calculation test code

#if 0
    SunriseSunsetData data;

    SunriseSunset_setPosition(
        &data,
        Types_bcdToDouble(
            Settings_data.location.latitudeBcd,
            Settings_data.location.latitudeSign
        ),
        Types_bcdToDouble(
            Settings_data.location.longitudeBcd,
            Settings_data.location.longitudeSign
        )
//        19.046867,
//        47.467442
    );
    SunriseSunset_setTimeZone(&data, 1, false);

    SunriseSunset_Time sunrise = SunriseSunset_calculate(&data, false, 28);
    SunriseSunset_Time sunset = SunriseSunset_calculate(&data, true, 28);

    char s[20];
    sprintf(s, "%2d:%02d, %2d:%02d",
        sunrise.hour, sunrise.minute,
        sunset.hour, sunset.minute
    );
    Text_draw(s, 7, 0, 0, false);
#endif

    __delay_ms(5000);
    SSD1306_clear();

    UI_init();

    System_onWakeUp(System_WakeUpReason_Startup);

    bool runHeavyTasks = true;

    System_TaskResult systemTaskResult = {
        .action = System_TaskResult_NoActionNeeded,
        .powerInputChanged = false
    };

    while (1)
    {
#if DEBUG_ENABLE
        static Clock_Ticks lastTicks = 0;
        if (Clock_getTicks() != lastTicks) {
            lastTicks = Clock_getTicks();
            UI_updateDebugDisplay();
        }
#endif

        Clock_task();

        if (runHeavyTasks) {
            uint8_t keyCode = Keypad_task();
    #if DEBUG_ENABLE_PRINT
            if (keyCode != 0) {
                printf(
                    "Keys(%02X): %1s %1s %1s %s\r\n",
                    keyCode,
                    keyCode & Keypad_Key1 ? "1" : "",
                    keyCode & Keypad_Key2 ? "2" : "",
                    keyCode & Keypad_Key3 ? "3" : "",
                    keyCode & Keypad_Hold ? "Hold" : ""
                );
            }
    #endif

            UI_keyEvent(keyCode);

            systemTaskResult = System_task();

            if (systemTaskResult.powerInputChanged) {
                UI_setExternalEvent(UI_ExternalEvent_PowerInputChanged);
            }

            if (context.adcConversionFinished) {
                context.adcConversionFinished = false;
                UI_setExternalEvent(UI_ExternalEvent_BatteryLevelMeasurementFinished);
            }

            if (systemTaskResult.action == System_TaskResult_EnterSleepMode) {
                UI_setExternalEvent(UI_ExternalEvent_SystemGoingToSleep);
            }

            UI_task();
        }

        if (OutputController_task() == OutputController_TaskResult_OutputStateChanged) {
            UI_setExternalEvent(UI_ExternalEvent_OutputStateChanged);
        }

        if (systemTaskResult.action == System_TaskResult_EnterSleepMode) {
#if DEBUG_ENABLE
            if (runHeavyTasks) {
                ++_DebugState.heavyTaskUpdateValue;
            }
#endif

            System_SleepResult sleepResult = System_sleep();

            runHeavyTasks =
                sleepResult == System_SleepResult_WakeUpFromExternalSource;

            if (runHeavyTasks) {
                UI_setExternalEvent(UI_ExternalEvent_SystemWakeUp);
#if DEBUG_ENABLE
                ++_DebugState.heavyTaskUpdateValue;
#endif
            } else {
                // Go back to sleep without running System_task()
                systemTaskResult.action = System_TaskResult_EnterSleepMode;
            }
        }
    }
}
/**
 End of File
*/

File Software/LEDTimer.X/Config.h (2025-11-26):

/*
    This file is part of LEDTimer.

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
    Author: Tamas Karpati
    Created on 2022-12-04
*/

#pragma once

#include "Types.h"

/**
 * General
 */
#define Config_FirmwareVersion                              "2.3.0"

/**
 * Settings
 */
#define Config_Settings_DataBaseAddress                     (0)
#define Config_Settings_IntervalScheduleCount               (5)

/**
 * System
 */
#define Config_System_StartupAwakeLengthTicks               (6)
#define Config_System_KeyPressWakeUpLengthTicks             (6)
#define Config_System_PowerInputChangeWakeUpLengthTicks     (6)
#define Config_System_MonitoringUpdateIntervalTicks         (2)

#define Config_System_VDDCalMilliVolts                      (3140ul)
#define Config_System_VDDCalADCValue                        (332ul)

#define Config_System_VBatDiodeDropMilliVolts               (270)

#define Config_System_VBatMinMilliVolts                     (2500u)
#define Config_System_VBatMaxMilliVolts                     (3000u)

/**
 * UI
 */
#define Config_UI_KeyRepeatIntervalTicks                    (10)
#define Config_UI_DisplayTimeoutTicks                       (1000)
#define Config_UI_UpdateIntervalTicks                       (100)

/**
 * Keypad
 */
#define Config_Keypad_ScanSampleCount                       (3)
#define Config_Keypad_ScanSamplingDelayUs                   (1)
#define Config_Keypad_DelayAfterKeysChangedTicks            (10)
#define Config_Keypad_RepeatTimeoutTicks                    (50)
#define Config_Keypad_RepeatIntervalTicks                   (10)
#define Config_Keypad_DeBounceCoolDownTicks                 (5)

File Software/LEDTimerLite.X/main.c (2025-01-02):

/*
    This file is part of LEDTimer.

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
    Author: Tamas Karpati
    Created on 2024-12-22
*/

#include "Clock.h"
#include "Config.h"
#include "OutputController.h"
#include "ProgrammingInterface.h"
#include "Settings.h"
#include "System.h"
#include "UserInterface.h"

#include <stdbool.h>

#include <xc.h>

static struct MainContext
{
    volatile uint8_t adcConversionFinished : 1;
    volatile uint8_t buttonPressed : 1;
    volatile uint8_t ldoSenseChanged : 1;
} Main_context = {
    .adcConversionFinished = 0,
    .buttonPressed = 0,
    .ldoSenseChanged = 0
};

void __interrupt() isr(void)
{
    // Timer1 (RTC)
    if (TMR1IE && TMR1IF) {
        TMR1IF = 0;
        Clock_handleRTCTimerInterrupt();
    }

    // Timer4 (FastTick)
    if (TMR4IE && TMR4IF) {
        TMR4IF = 0;
        Clock_handleFastTimerInterrupt();
    }

    // ADC
    if (ADIE && ADIF) {
        ADIF = 0;
        System_handleADCInterrupt(((uint16_t)ADRESH) << 8 | ADRESL);
        Main_context.adcConversionFinished = 1;
    }

    // UART RC (Programming Interface)
    if (RCIE && RCIF) {
        char c = RCREG;
        ProgrammingInterface_processInputChar(c);
    }

    // GPIO Interrupt-on-change
    if (IOCIE && IOCIF) {
        // RC3 IOC - SW
        if (IOCCF3) {
            IOCCF3 = 0;
            Main_context.buttonPressed = 1;
//            System_handleExternalWakeUp();
            ProgrammingInterface_logEvent(PI_LOG_ButtonPress);
        }

        // RA2 IOC - LDO_SENSE
        if (IOCAF2) {
            IOCAF2 = 0;
            Main_context.ldoSenseChanged = 1;
            ProgrammingInterface_logEvent(
                RA2 == 1 ? PI_LOG_LDOPowerDown : PI_LOG_LDOPowerUp
            );
        }
    }
}

inline static void showStartupScreen()
{
    if (PCON0bits.STKOVF) {
        PCON0bits.STKOVF = 0;
    }

    if (PCON0bits.STKUNF) {
        PCON0bits.STKUNF = 0;
    }

    if (!PCON0bits.nRWDT) {
        PCON0bits.nRWDT = 1;
    }

    if (!PCON0bits.nRMCLR) {
        PCON0bits.nRMCLR = 1;
    }

    if (!PCON0bits.nRI) {
        PCON0bits.nRI = 1;
    }

    if (BORRDY && !PCON0bits.nBOR) {
        PCON0bits.nBOR = 1;
    }
}

void main(void)
{
    System_init();

    Settings_init();
    Settings_load();

    ProgrammingInterface_init();
    ProgrammingInterface_logEvent(PI_LOG_Startup);

    UserInterface_init();

    while (true) {
        if (System_isRunningFromBackupBattery()) {
            // Do only minimal number of tasks to save power

            // Block sleep if UI has pending lightweight tasks
            if (!UserInterface_hasPendingLightweightTasks()) {
                System_prepareForSleepMode();
                SLEEP();
                System_runTasksAfterWakeUp();
            }
        } else {
            // We have external power, do every task

            Clock_runTasks();

            if (OutputController_runTasks() == OutputController_TaskResult_OutputStateChanged) {
                UserInterface_handleExternalEvent(UI_ExternalEvent_OutputStateChanged);
            }

            UserInterface_runTasks();

            ProgrammingInterface_runTasks();
        }

        // Handle button press
        if (Main_context.buttonPressed) {
            Main_context.buttonPressed = 0;
            UserInterface_buttonPressEvent();
        }

        // Handle LDO sense changes
        if (Main_context.ldoSenseChanged) {
            Main_context.ldoSenseChanged = 0;
            UserInterface_handleExternalEvent(UI_ExternalEvent_PowerInputChanged);
        }

        UserInterface_runLightweightTasks();
    }
}

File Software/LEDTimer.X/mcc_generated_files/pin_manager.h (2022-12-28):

/**
  @Generated Pin Manager Header File

  @Company:
    Microchip Technology Inc.

  @File Name:
    pin_manager.h

  @Summary:
    This is the Pin Manager file generated using PIC10 / PIC12 / PIC16 / PIC18 MCUs

  @Description
    This header file provides APIs for driver for .
    Generation Information :
        Product Revision  :  PIC10 / PIC12 / PIC16 / PIC18 MCUs - 1.81.8
        Device            :  PIC16F18326
        Driver Version    :  2.11
    The generated drivers are tested against the following:
        Compiler          :  XC8 2.36 and above
        MPLAB 	          :  MPLAB X 6.00	
*/

/*
    (c) 2018 Microchip Technology Inc. and its subsidiaries. 
    
    Subject to your compliance with these terms, you may use Microchip software and any 
    derivatives exclusively with Microchip products. It is your responsibility to comply with third party 
    license terms applicable to your use of third party software (including open source software) that 
    may accompany Microchip software.
    
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
    IN NO EVENT WILL MICROCHIP BE LIABLE FOR ANY INDIRECT, SPECIAL, PUNITIVE, 
    INCIDENTAL OR CONSEQUENTIAL LOSS, DAMAGE, COST OR EXPENSE OF ANY KIND 
    WHATSOEVER RELATED TO THE SOFTWARE, HOWEVER CAUSED, EVEN IF MICROCHIP 
    HAS BEEN ADVISED OF THE POSSIBILITY OR THE DAMAGES ARE FORESEEABLE. TO 
    THE FULLEST EXTENT ALLOWED BY LAW, MICROCHIP'S TOTAL LIABILITY ON ALL 
    CLAIMS IN ANY WAY RELATED TO THIS SOFTWARE WILL NOT EXCEED THE AMOUNT 
    OF FEES, IF ANY, THAT YOU HAVE PAID DIRECTLY TO MICROCHIP FOR THIS 
    SOFTWARE.
*/

#ifndef PIN_MANAGER_H
#define PIN_MANAGER_H

/**
  Section: Included Files
*/

#include <xc.h>

#define INPUT   1
#define OUTPUT  0

#define HIGH    1
#define LOW     0

#define ANALOG      1
#define DIGITAL     0

#define PULL_UP_ENABLED      1
#define PULL_UP_DISABLED     0

// get/set IO_SW1 aliases
#define IO_SW1_TRIS                 TRISAbits.TRISA0
#define IO_SW1_LAT                  LATAbits.LATA0
#define IO_SW1_PORT                 PORTAbits.RA0
#define IO_SW1_WPU                  WPUAbits.WPUA0
#define IO_SW1_OD                   ODCONAbits.ODCA0
#define IO_SW1_ANS                  ANSELAbits.ANSA0
#define IO_SW1_SetHigh()            do { LATAbits.LATA0 = 1; } while(0)
#define IO_SW1_SetLow()             do { LATAbits.LATA0 = 0; } while(0)
#define IO_SW1_Toggle()             do { LATAbits.LATA0 = ~LATAbits.LATA0; } while(0)
#define IO_SW1_GetValue()           PORTAbits.RA0
#define IO_SW1_SetDigitalInput()    do { TRISAbits.TRISA0 = 1; } while(0)
#define IO_SW1_SetDigitalOutput()   do { TRISAbits.TRISA0 = 0; } while(0)
#define IO_SW1_SetPullup()          do { WPUAbits.WPUA0 = 1; } while(0)
#define IO_SW1_ResetPullup()        do { WPUAbits.WPUA0 = 0; } while(0)
#define IO_SW1_SetPushPull()        do { ODCONAbits.ODCA0 = 0; } while(0)
#define IO_SW1_SetOpenDrain()       do { ODCONAbits.ODCA0 = 1; } while(0)
#define IO_SW1_SetAnalogMode()      do { ANSELAbits.ANSA0 = 1; } while(0)
#define IO_SW1_SetDigitalMode()     do { ANSELAbits.ANSA0 = 0; } while(0)

// get/set IO_SW2 aliases
#define IO_SW2_TRIS                 TRISAbits.TRISA1
#define IO_SW2_LAT                  LATAbits.LATA1
#define IO_SW2_PORT                 PORTAbits.RA1
#define IO_SW2_WPU                  WPUAbits.WPUA1
#define IO_SW2_OD                   ODCONAbits.ODCA1
#define IO_SW2_ANS                  ANSELAbits.ANSA1
#define IO_SW2_SetHigh()            do { LATAbits.LATA1 = 1; } while(0)
#define IO_SW2_SetLow()             do { LATAbits.LATA1 = 0; } while(0)
#define IO_SW2_Toggle()             do { LATAbits.LATA1 = ~LATAbits.LATA1; } while(0)
#define IO_SW2_GetValue()           PORTAbits.RA1
#define IO_SW2_SetDigitalInput()    do { TRISAbits.TRISA1 = 1; } while(0)
#define IO_SW2_SetDigitalOutput()   do { TRISAbits.TRISA1 = 0; } while(0)
#define IO_SW2_SetPullup()          do { WPUAbits.WPUA1 = 1; } while(0)
#define IO_SW2_ResetPullup()        do { WPUAbits.WPUA1 = 0; } while(0)
#define IO_SW2_SetPushPull()        do { ODCONAbits.ODCA1 = 0; } while(0)
#define IO_SW2_SetOpenDrain()       do { ODCONAbits.ODCA1 = 1; } while(0)
#define IO_SW2_SetAnalogMode()      do { ANSELAbits.ANSA1 = 1; } while(0)
#define IO_SW2_SetDigitalMode()     do { ANSELAbits.ANSA1 = 0; } while(0)

// get/set IO_LDO_SENSE aliases
#define IO_LDO_SENSE_TRIS                 TRISAbits.TRISA2
#define IO_LDO_SENSE_LAT                  LATAbits.LATA2
#define IO_LDO_SENSE_PORT                 PORTAbits.RA2
#define IO_LDO_SENSE_WPU                  WPUAbits.WPUA2
#define IO_LDO_SENSE_OD                   ODCONAbits.ODCA2
#define IO_LDO_SENSE_ANS                  ANSELAbits.ANSA2
#define IO_LDO_SENSE_SetHigh()            do { LATAbits.LATA2 = 1; } while(0)
#define IO_LDO_SENSE_SetLow()             do { LATAbits.LATA2 = 0; } while(0)
#define IO_LDO_SENSE_Toggle()             do { LATAbits.LATA2 = ~LATAbits.LATA2; } while(0)
#define IO_LDO_SENSE_GetValue()           PORTAbits.RA2
#define IO_LDO_SENSE_SetDigitalInput()    do { TRISAbits.TRISA2 = 1; } while(0)
#define IO_LDO_SENSE_SetDigitalOutput()   do { TRISAbits.TRISA2 = 0; } while(0)
#define IO_LDO_SENSE_SetPullup()          do { WPUAbits.WPUA2 = 1; } while(0)
#define IO_LDO_SENSE_ResetPullup()        do { WPUAbits.WPUA2 = 0; } while(0)
#define IO_LDO_SENSE_SetPushPull()        do { ODCONAbits.ODCA2 = 0; } while(0)
#define IO_LDO_SENSE_SetOpenDrain()       do { ODCONAbits.ODCA2 = 1; } while(0)
#define IO_LDO_SENSE_SetAnalogMode()      do { ANSELAbits.ANSA2 = 1; } while(0)
#define IO_LDO_SENSE_SetDigitalMode()     do { ANSELAbits.ANSA2 = 0; } while(0)

// get/set RC0 procedures
#define RC0_SetHigh()            do { LATCbits.LATC0 = 1; } while(0)
#define RC0_SetLow()             do { LATCbits.LATC0 = 0; } while(0)
#define RC0_Toggle()             do { LATCbits.LATC0 = ~LATCbits.LATC0; } while(0)
#define RC0_GetValue()              PORTCbits.RC0
#define RC0_SetDigitalInput()    do { TRISCbits.TRISC0 = 1; } while(0)
#define RC0_SetDigitalOutput()   do { TRISCbits.TRISC0 = 0; } while(0)
#define RC0_SetPullup()             do { WPUCbits.WPUC0 = 1; } while(0)
#define RC0_ResetPullup()           do { WPUCbits.WPUC0 = 0; } while(0)
#define RC0_SetAnalogMode()         do { ANSELCbits.ANSC0 = 1; } while(0)
#define RC0_SetDigitalMode()        do { ANSELCbits.ANSC0 = 0; } while(0)
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

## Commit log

2022-12-01 Add PCB design files
    [LEDTimer.kicad_pcb, LEDTimer.kicad_sch]
2022-12-02 Add option to invert text and graphics
    [Graphics.h, main.c]
2022-12-02 Implement keypad de-bouncing logic
2022-12-02 Handle keys in UI, implement auto display power control
2022-12-03 Add LED activity indicator icon
2022-12-03 Add external power indicator
2022-12-04 Avoid display artifacts on battery
2022-12-04 Update the resistor values of the LDO_SENSE divider
    [LEDTimer.kicad_sch]
2022-12-04 Use proper function prototypes in the headers
2022-12-04 Implement battery voltage measurement and power input switchover detection
2022-12-04 Workaround a potential stack overflow in main()
    [main.c]
2022-12-04 Handle power input changes properly
2022-12-04 Add missing values to I2C pull-up resistors
    [LEDTimer.kicad_sch]
2022-12-04 Conserve more power by turning off the FVR in sleep mode
2022-12-05 Optimize the code to avoid potential stack overflows, centralize the config
    [Config.h, System.c, main.c]
2022-12-05 Initial commit of switching between screens
2022-12-09 Implement page switching logic in Settings screen
2022-12-10 Update battery indicator after starting up from battery
2022-12-10 Add prototype images
2022-12-10 Add more prototype images
2022-12-10 Add images of the prototype
2022-12-10 Add image of the prototype setup
2022-12-10 Add PCB and enclosuse info to Readme
2022-12-10 Fix missing clock setting title
    [Config.h]
2022-12-13 PCB: add footprint libraries
    [LEDTimer.kicad_pcb, LEDTimer.kicad_sch, Renata_-_HU2032-LF.step]
2022-12-13 PCB: start laying out the board
    [LEDTimer.kicad_pcb, LEDTimer.kicad_sch]
2022-12-14 PCB: first version of the layout
    [LEDTimer.kicad_pcb, LEDTimer.kicad_sch]
2022-12-21 PCB: new layout (not routed yet)
    [LEDTimer.kicad_pcb, LEDTimer.kicad_sch, SC-74-6.stp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]
2022-12-21 PCB: update and add new models
    [1825232-1 v7.step, BU2032-1-HD-G.stp, LEDTimer.kicad_pcb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]
2022-12-21 PCB: move the switches closer to the edge
    [LEDTimer.kicad_pcb]
2022-12-22 PCB: use a 4-layer design
    [LEDTimer.kicad_pcb, LEDTimer.kicad_sch]
2022-12-22 PCB: fix DRC issues
    [LEDTimer.kicad_pcb, LEDTimer.kicad_sch]
2022-12-22 PCB: flip the power input connector
    [LEDTimer.kicad_pcb, LEDTimer.kicad_sch]
2022-12-27 PCB: re-purpose the switch as main power switch, add a transistor to LDO_SENSE for protection
    [LEDTimer.kicad_pcb, LEDTimer.kicad_sch]
2022-12-28 PCB: add interactive BOM
    [LEDTimer.kicad_pcb, LEDTimer.kicad_sch]
2022-12-28 PCB: 3D renders
2022-12-28 Add PCB details to README
2022-12-28 PCB: add pull-down resistor to LED_EN_PWM
    [LEDTimer.kicad_pcb, LEDTimer.kicad_sch]
2022-12-28 Switch to PIC16F18326
2022-12-28 Fix issues and warnings after PIC transition
    [main.c]
2022-12-28 Fix output pin mapping
    [pin_manager.h]
2022-12-28 PCB: swap the MCU to 16F18326
    [LEDTimer.kicad_pcb, LEDTimer.kicad_sch]
2022-12-28 Update estimated sleep power consumption and battery life in README
2022-12-28 Tweak the config, set the default PWM5 DC value to 0
2023-01-01 PCB: adjust the footprint of RVext1
    [LEDTimer.kicad_pcb]
2023-01-02 Case: start designing the case
    [LEDTimer-Case-v1.FCStd, LEDTimer.kicad_pcb]
2023-01-02 Case: add cut-outs for the buttons
    [LEDTimer-Case-v1.FCStd]
2023-01-02 Case: adjust button cut-outs to be 3D-printable
    [LEDTimer-Case-v1.FCStd]
2023-01-02 Case: add cut-outs for the connectors and the trimmer
    [LEDTimer-Case-v1.FCStd]
2023-01-02 Case: add the bottom part
    [LEDTimer-Case-v1.FCStd]
2023-01-02 Case: finish the bottom part
    [LEDTimer-Case-v1.FCStd]
2023-01-02 Case: add preview images
    [LEDTimer-Case-v1.FCStd]
2023-01-02 Add preview images of the case to the Readme
2023-01-14 Fix issues with PIC16F18326
    [System.c]
2023-01-18 Fix waking up from sleep mode; slow down I2C for more stability
    [System.c]
2023-01-19 Fix the scheduler logic in the output controller
    [Config.h, OutputController.c]
2023-01-19 Decrease I2C speed to standard 400 kHz
2023-01-19 Add reset reason indicator to the splash screen
    [main.c]
2023-01-19 Disable BOR since it triggers unnecessarily on some devices
2023-01-19 Fix Types_getScheduleSegmentBit() to return a binary value
    [OutputController.c]
2023-01-21 Update deep-sleep consumption and battery life
2023-01-21 Enable VREGPM to conserve more power in sleep mode
2023-01-21 Optimize background clearing of power indicator, wake the screen on power input change
2023-01-29 Print test sunrise/sunset data on the splash screen
2023-02-17 Fix location setting issues, bump version
    [Config.h, main.c]
2023-02-19 Add design file for LED toggle indicator
2023-02-20 Optimize a little bit more in the OLED driver
2023-02-20 Optimize/de-duplicate string literals
2023-03-14 Implement settings for multi-schedule interval timer
2023-04-02 Add LedTimerSchedulerPlayground
2023-04-02 Fix GitHub directory in LedTimerSchedulerPlayground
2023-04-06 Replace memset() calls to spare flash space
    [SettingsScreen_LEDBrightness.c]
2023-04-06 Fix non-updating switch type on schedule index change
2023-06-01 Case: update button design (WIP)
    [LEDTimer-Case-v1.FCStd]
2023-06-05 Case: update front piece design to make buttons usable
    [LEDTimer-Case-v1.FCStd]
2023-06-05 Case: add factory files
2023-06-05 Case: adjust part positions
    [LEDTimer-Case-v1.FCStd]
2023-06-05 Add new case images
2023-06-10 LedTimerSchedulerPlayground: add GetNextTransitionV2
2023-11-26 Reduce OLED contrast on battery
2024-10-01 Reduce LUT size by 50%
    By limiting the precision to 6 minute "buckets",
    sunrise and sunset times can be stored on 8 bits
    instead of 16 bits.
2024-10-02 Switch to C calendar API
2024-10-02 Switch to XC8 v2.49 FuSa
    This compiler generates the smallest code so far.
    It's also a Functional Safety version.
2024-12-09 Add LED Timer Lite
    [1825232-1 v7.step, BU2032-1-HD-G.stp, LEDTimerLite.kicad_pcb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]
2024-12-10 LTL: try new PCB layout
    [LEDTimerLite.kicad_pcb, LEDTimerLite.kicad_sch]
2024-12-12 LTL: improve track routing
    [LEDTimerLite.kicad_pcb, LEDTimerLite.kicad_sch]
2024-12-13 LTL: replace BAT54C with 1SS384 (lower Vf)
    [LEDTimerLite.kicad_pcb, LEDTimerLite.kicad_sch]
2024-12-13 LTL: fix ERC issues
    [LEDTimerLite.kicad_pcb, LEDTimerLite.kicad_sch]
2024-12-13 LTL: fix DRC issues
    [LEDTimerLite.kicad_pcb]
2024-12-13 LTL: add extra test points, optimize layout
    [LEDTimerLite.kicad_pcb, LEDTimerLite.kicad_sch]
2024-12-13 LTL: replace LED driver and RVext1
    Use BCR321U (250 mA) instead of BCR421U (150 mA).
    Use TC33X-2-101E as RVext1 because it's cheaper.
    [LEDTimerLite.kicad_pcb, LEDTimerLite.kicad_sch, TC33X-2-101E.stp]
2024-12-16 LTL: add debouncing capacitor to SW
    [LEDTimerLite.kicad_pcb, LEDTimerLite.kicad_sch]
2024-12-22 LTL: implement indicator LED control logic
2025-01-02 LTL: cleanup Clock's timer code
2025-11-26 Preview LED brightness in settings

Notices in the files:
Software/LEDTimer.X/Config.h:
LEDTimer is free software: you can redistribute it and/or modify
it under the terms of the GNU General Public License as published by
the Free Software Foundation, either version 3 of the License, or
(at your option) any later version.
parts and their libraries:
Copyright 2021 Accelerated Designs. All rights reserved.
